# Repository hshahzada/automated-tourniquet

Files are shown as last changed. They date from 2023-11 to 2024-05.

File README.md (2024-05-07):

View this project on [CADLAB.io](https://cadlab.io/project/27395). 

# automated-tourniquet
2023/2024 Capstone Design Project for Biomedical Engineering

Created by:

Diana Temelkos dtemelkos@torontomu.ca
https://www.linkedin.com/in/dianatemelkos/

Hassan Khan hassan.a.khan@torontomu.ca
https://www.linkedin.com/in/hassan-khan-5604501a9/

Haashim Shahzada hshahzada@torontomu.ca
https://www.linkedin.com/in/haashimshahzada/

Sayeed Hasan sayeed.hasan@torontomu.ca
https://www.linkedin.com/in/sayeedhasanli/

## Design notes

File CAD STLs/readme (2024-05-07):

All files can be combined to simulate a replica DH3 Automated Tourniquet. 
All STLs were created using OnShape and 3D printed to create the design.

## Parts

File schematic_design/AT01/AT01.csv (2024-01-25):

Source: | D:\Haashim Shahzada\Documents\github\automated-tourniquet\schematic_design\AT01\AT01.kicad_sch
Date: | 1/21/2024 3:26:29 AM
Tool: | Eeschema 7.0.8
Generator: | C:\Program Files\KiCad\7.0\bin\scripting\plugins/bom_csv_grouped_by_value.py
Component Count: | 58
Collated Components:
Item | Qty | Reference(s) | Value | LibPart | Footprint | Datasheet | DNP
1 | 1 | C1 | 0.1uF | Device:C_Small | Capacitor_SMD:C_0402_1005Metric_Pad0.74x0.62mm_HandSolder | ~
2 | 1 | C2 | 1nF | Device:C_Small | Capacitor_SMD:C_0402_1005Metric_Pad0.74x0.62mm_HandSolder | ~
3 | 1 | C3 | 2.2uF | Device:C | Capacitor_SMD:C_0402_1005Metric_Pad0.74x0.62mm_HandSolder | ~
4 | 1 | C4 | 0.01uF | Device:C | Capacitor_SMD:C_0402_1005Metric_Pad0.74x0.62mm_HandSolder | ~
5 | 1 | C5 | 1uF | Device:C | Capacitor_SMD:C_0402_1005Metric_Pad0.74x0.62mm_HandSolder | ~
6 | 3 | C6, C8, C11 | 10uF | Device:C | Capacitor_SMD:C_0402_1005Metric_Pad0.74x0.62mm_HandSolder | ~
7 | 1 | C7 | 4.7uF | Device:C | Capacitor_SMD:C_0402_1005Metric_Pad0.74x0.62mm_HandSolder | ~
8 | 1 | C10 | 100uF | Device:C | Capacitor_SMD:C_0402_1005Metric_Pad0.74x0.62mm_HandSolder | ~
9 | 1 | C13 | 10uF | Device:C_Polarized_Small_US | Capacitor_SMD:C_1206_3216Metric_Pad1.33x1.80mm_HandSolder | ~
10 | 1 | C14 | 100uF | 2023-10-27_15-39-09:EEE-FN1A101UR | CAP_FN_C_PAN | EEE-FN1A101UR
11 | 2 | D1, D6 | B120-E3 | Diode:B120-E3 | Diode_SMD:D_SMA | http://www.vishay.com/docs/88946/b120.pdf
12 | 3 | D2, D7, D8 | LED | Device:LED | LED_THT:LED_D3.0mm | ~
13 | 3 | D3, D4, D5 | ESD9B3.3ST5G | Diode:ESD9B3.3ST5G | Diode_SMD:D_SOD-923 | https://www.onsemi.com/pub/Collateral/ESD9B-D.PDF
14 | 4 | H1, H2, H3, H4 | MountingHole | Mechanical:MountingHole | MountingHole:MountingHole_2.2mm_M2_ISO7380 | ~
15 | 1 | J1 | JST Connector | Connector:Screw_Terminal_01x02 | Connector_JST:JST_EH_S2B-EH_1x02_P2.50mm_Horizontal | ~
16 | 1 | J2 | Conn_01x08 | Connector_Generic:Conn_01x08 | Connector_PinHeader_1.00mm:PinHeader_1x08_P1.00mm_Vertical | ~
17 | 1 | J3 | USB_C_Receptacle_USB2.0 | Connector:USB_C_Receptacle_USB2.0 | Connector_USB:USB_C_Receptacle_HRO_TYPE-C-31-M-12 | https://www.usb.org/sites/default/files/documents/usb_type-c.zip
18 | 1 | J4 | DC Pump Connector | Connector:Screw_Terminal_01x02 | TerminalBlock_4Ucon:TerminalBlock_4Ucon_1x02_P3.50mm_Vertical | ~
19 | 1 | J5 | Solenoid Valve Connector | Connector:Screw_Terminal_01x02 | TerminalBlock_4Ucon:TerminalBlock_4Ucon_1x02_P3.50mm_Vertical | ~
20 | 1 | Q1 | DMG2301L | Transistor_FET:DMG2301L | Package_TO_SOT_SMD:SOT-23 | https://www.diodes.com/assets/Datasheets/DMG2301L.pdf
21 | 2 | Q2, Q3 | 2N7002 | Transistor_FET:2N7002 | Package_TO_SOT_SMD:SOT-23 | https://www.onsemi.com/pub/Collateral/NDS7002A-D.PDF
22 | 8 | R1, R5, R6, R7, R9, R10, R14, R15 | 5.1K | Device:R | Resistor_SMD:R_0402_1005Metric_Pad0.72x0.64mm_HandSolder | ~
23 | 3 | R2, R12, R13 | 2.2K | Device:R | Resistor_SMD:R_0402_1005Metric_Pad0.72x0.64mm_HandSolder | ~
24 | 1 | R3 | 100K | Device:R | Resistor_SMD:R_0402_1005Metric_Pad0.72x0.64mm_HandSolder | ~
25 | 4 | R4, R11, R16, R17 | 10K | Device:R | Resistor_SMD:R_0402_1005Metric_Pad0.72x0.64mm_HandSolder | ~
26 | 1 | R8 | 20K | Device:R | Resistor_SMD:R_0402_1005Metric_Pad0.72x0.64mm_HandSolder | ~
27 | 3 | SW1, SW2, SW3 | SW_Push | Switch:SW_Push | Button_Switch_THT:SW_PUSH_6mm | ~
28 | 1 | U1 | MPRLS0025PA00001A | MPRLS0025PA00001A:MPRLS0025PA00001A | MPRLS_HNW | MPRLS0025PA00001A
29 | 1 | U2 | FT232RL | Interface_USB:FT232RL | Package_SO:SSOP-28_5.3x10.2mm_P0.65mm | https://www.ftdichip.com/Support/Documents/DataSheets/ICs/DS_FT232R.pdf
30 | 1 | U3 | DRV8833PW | Driver_Motor:DRV8833PW | Package_SO:TSSOP-16_4.4x5mm_P0.65mm | http://www.ti.com/lit/ds/symlink/drv8833.pdf
31 | 1 | U4 | MCP73831-2-OT | Battery_Management:MCP73831-2-OT | Package_TO_SOT_SMD:SOT-23-5 | http://ww1.microchip.com/downloads/en/DeviceDoc/20001984g.pdf
32 | 1 | U5 | ESP32-WROOM-32 | RF_Module:ESP32-WROOM-32U | RF_Module:ESP32-WROOM-32UE | https://www.espressif.com/sites/default/files/documentation/esp32-wroom-32d_esp32-wroom-32u_datasheet_en.pdf
33 | 1 | U6 | LM1117MP-3.3 | Regulator_Linear:LM1117MP-3.3 | Package_TO_SOT_SMD:SOT-223-3_TabPin2 | http://www.ti.com/lit/ds/symlink/lm1117.pdf

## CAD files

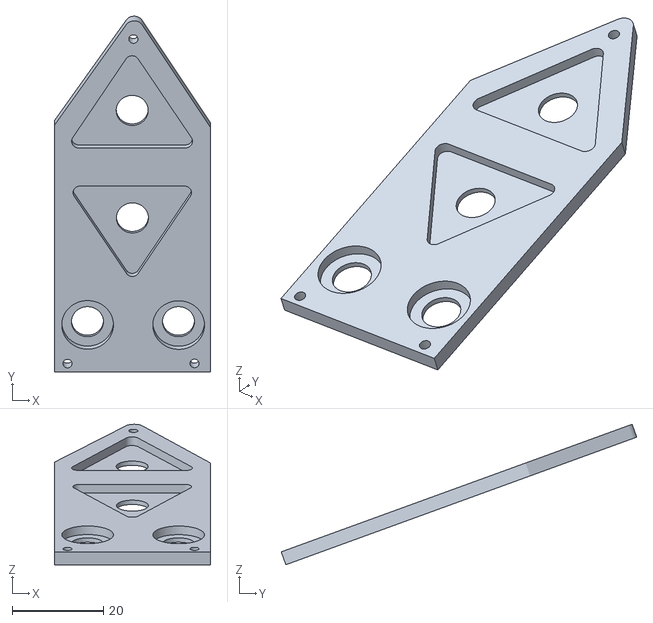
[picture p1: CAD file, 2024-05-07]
CAD STLs/AT01 - button setter.stl
34.1 x 77.8 x 30.8

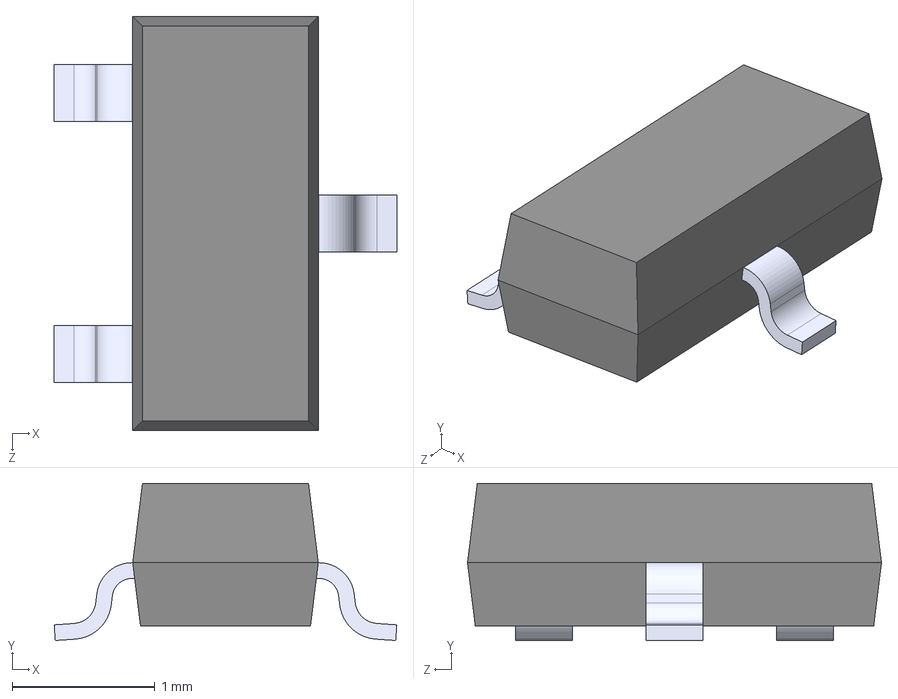
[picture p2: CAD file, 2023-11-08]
schematic_design/AT01/DMG3415U-7/DMG3415U-7.step
2.40 x 1.10 x 2.90 mm

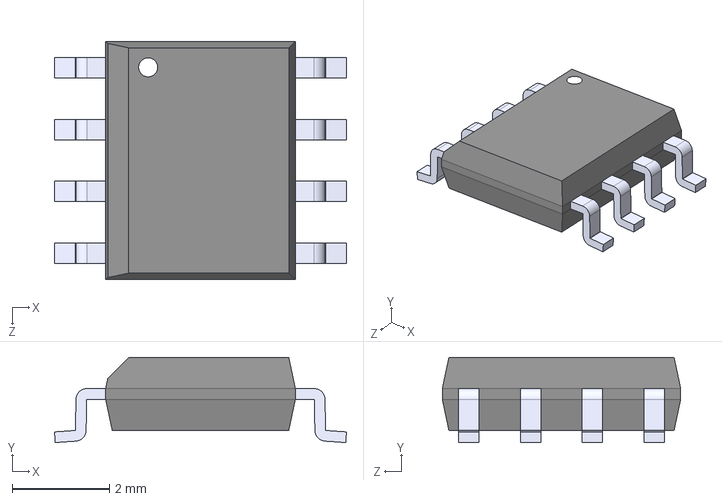
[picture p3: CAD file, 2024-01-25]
schematic_design/AT01/FDS6375/FDS6375.step
6.00 x 1.75 x 4.90 mm

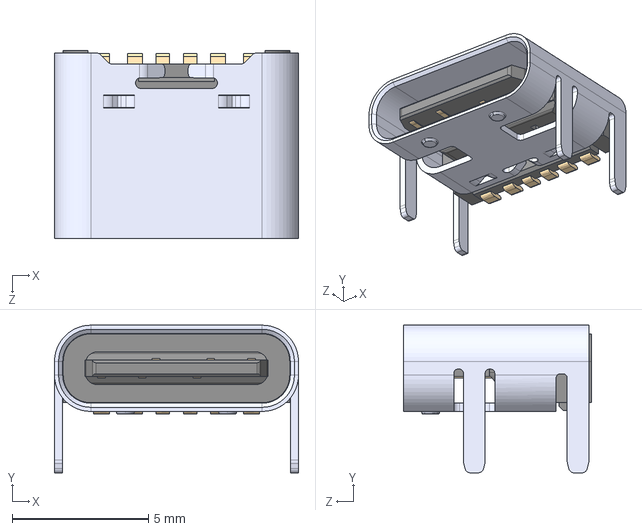
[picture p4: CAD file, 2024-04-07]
schematic_design/AT01/USB4125_GF_A_0190/USB4125-GF-A-0190_REVA2.step
8.94 x 5.41 x 6.90 mm

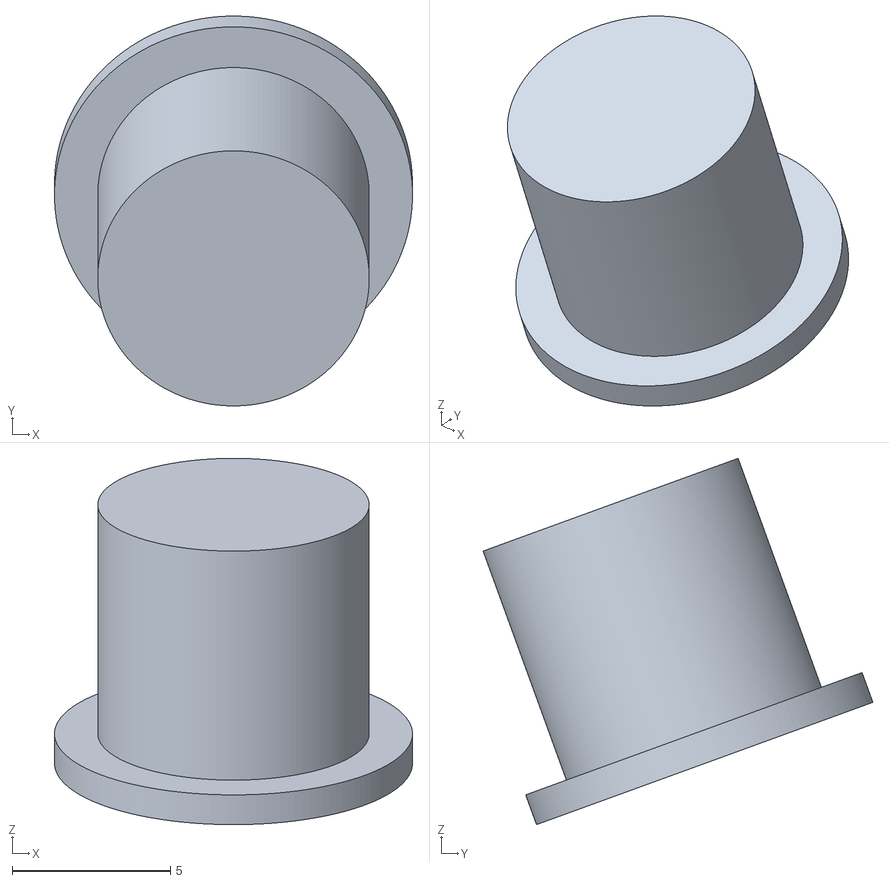
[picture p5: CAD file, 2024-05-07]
CAD STLs/AT01 - power.stl
11.3 x 12.3 x 11.6

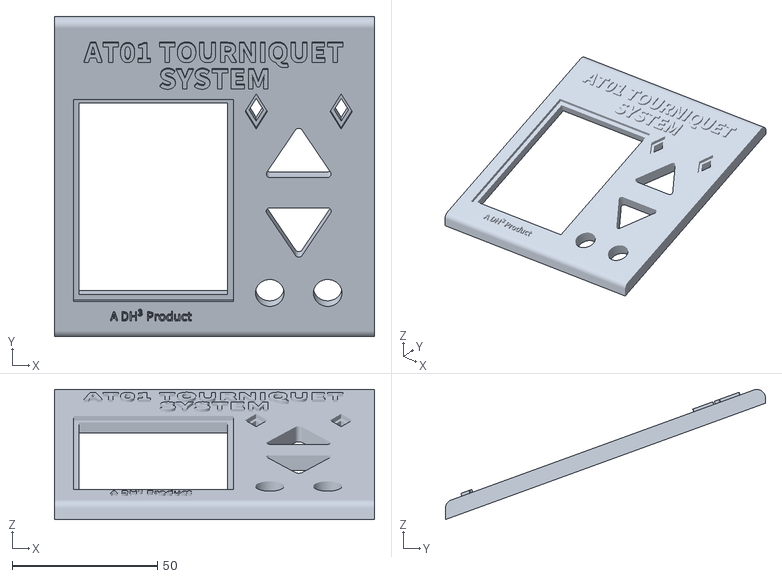
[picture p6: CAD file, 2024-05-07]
CAD STLs/AT01 - top-cover.stl
110.0 x 110.0 x 44.7

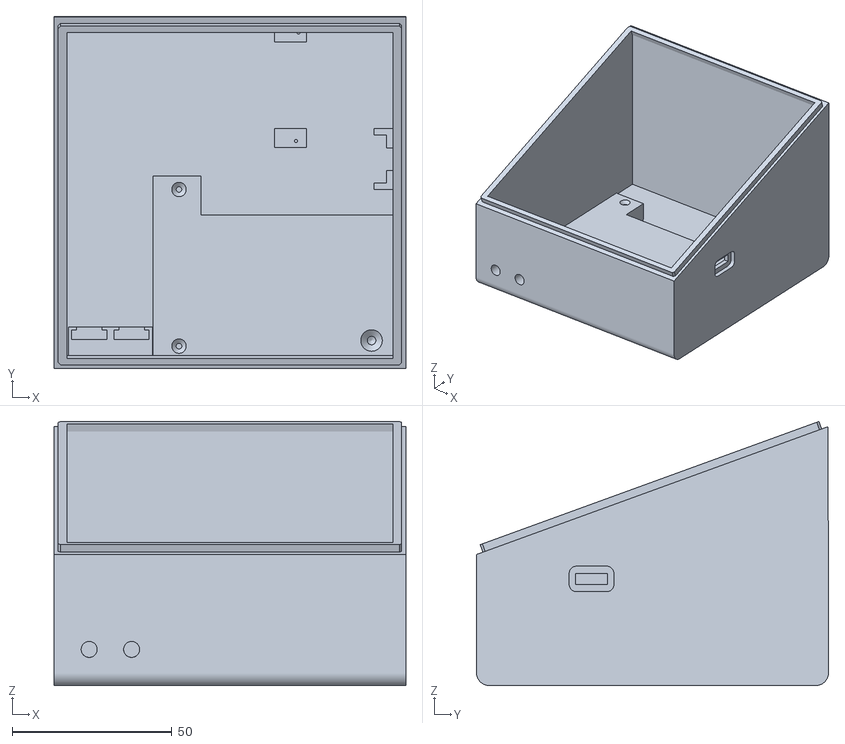
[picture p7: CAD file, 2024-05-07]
CAD STLs/AT01 - bottom.stl
110.0 x 110.1 x 82.6

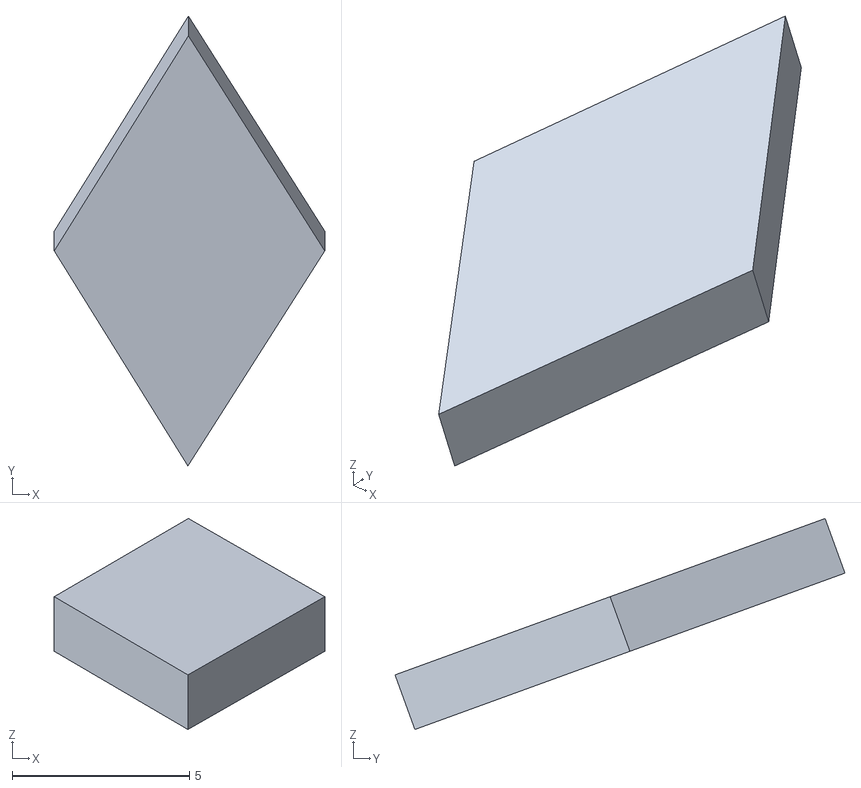
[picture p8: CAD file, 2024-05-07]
CAD STLs/AT01 - light 1 cover.stl
7.63 x 12.7 x 5.96

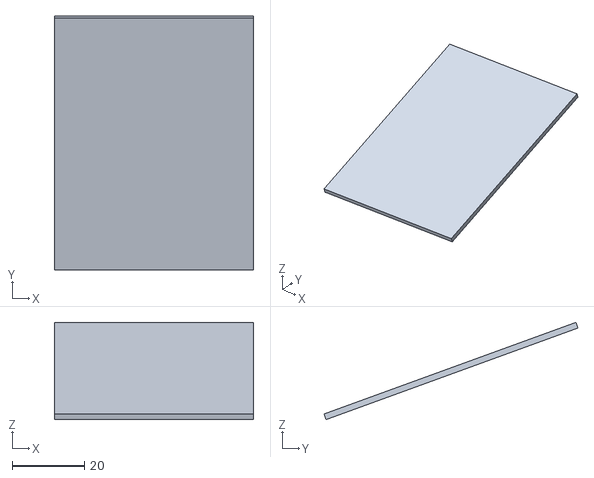
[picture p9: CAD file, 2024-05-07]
CAD STLs/AT01 - display protector.stl
55.0 x 70.1 x 26.8

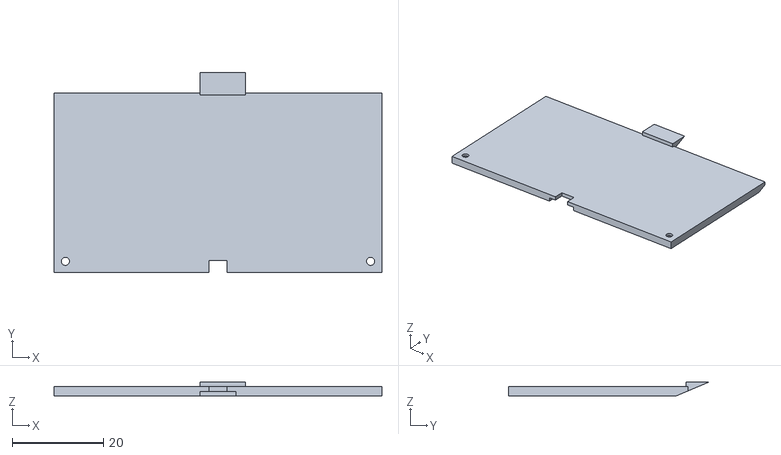
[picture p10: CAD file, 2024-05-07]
CAD STLs/AT01 - battery cover.stl
72.0 x 44.0 x 3.00

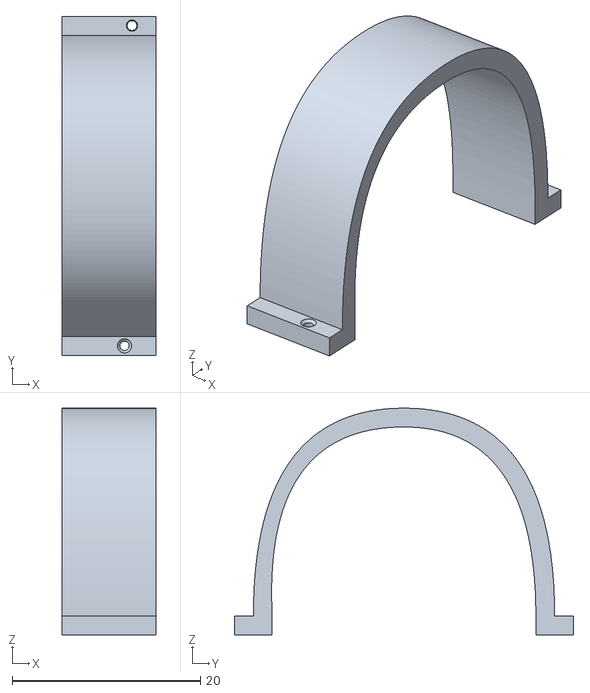
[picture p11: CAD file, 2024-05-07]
CAD STLs/AT01 - fastener.stl
10.0 x 36.0 x 24.1

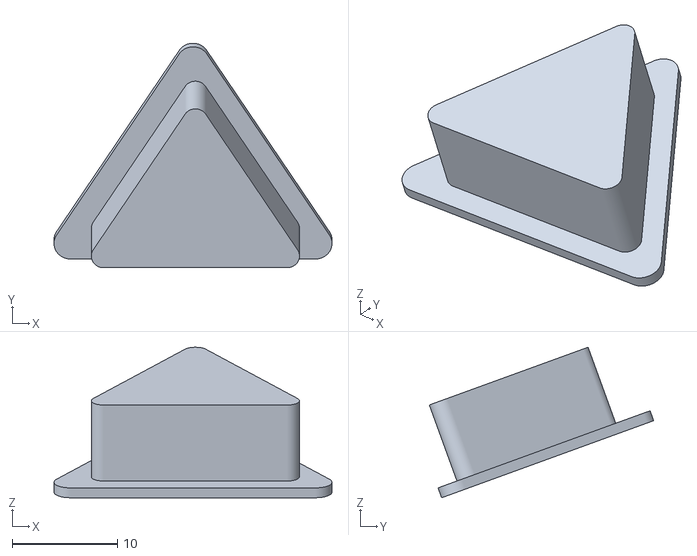
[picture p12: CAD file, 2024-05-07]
CAD STLs/AT01 - down.stl
26.5 x 21.4 x 14.3

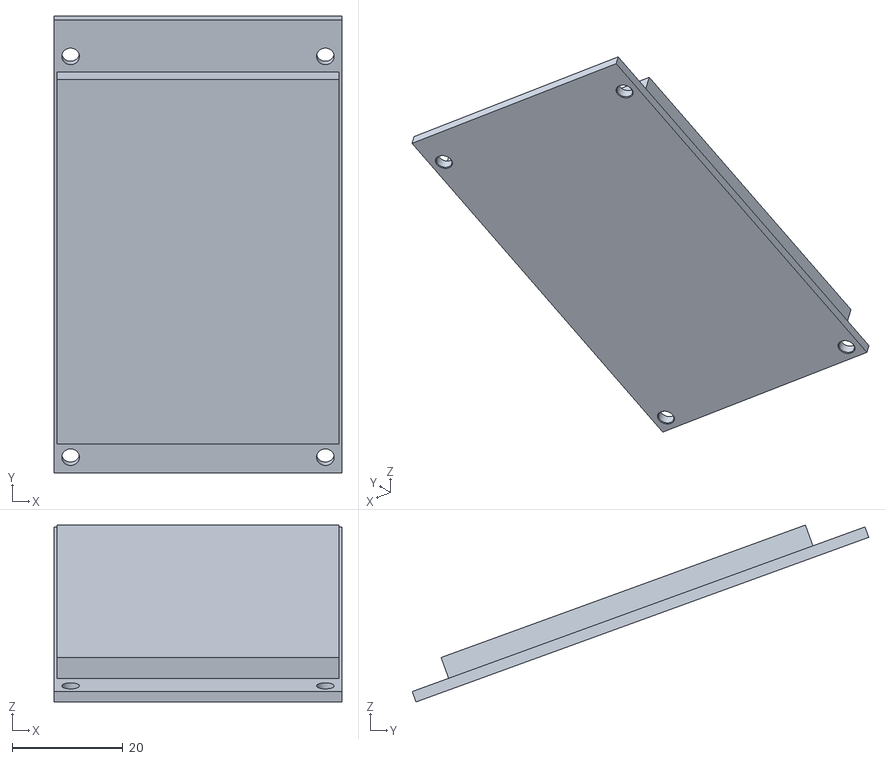
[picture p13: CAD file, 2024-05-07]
CAD STLs/AT01 - display.stl
52.0 x 82.4 x 32.0

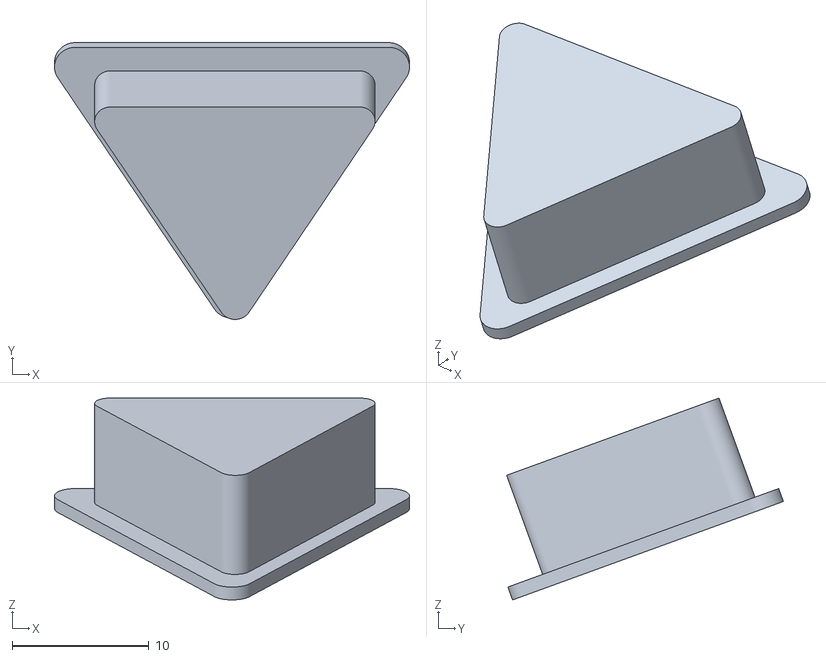
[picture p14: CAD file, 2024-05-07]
CAD STLs/AT01 - up.stl
25.9 x 20.2 x 14.7

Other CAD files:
CAD STLs/AT01 - reset.stl
CAD STLs/AT01 - internal pneum inlet 2.stl
CAD STLs/AT01 - pcb.stl
CAD STLs/AT01 - internal pneum inlet 1.stl
CAD STLs/AT01 - cuff inlet piece.stl
CAD STLs/AT01 - light 2 cover.stl

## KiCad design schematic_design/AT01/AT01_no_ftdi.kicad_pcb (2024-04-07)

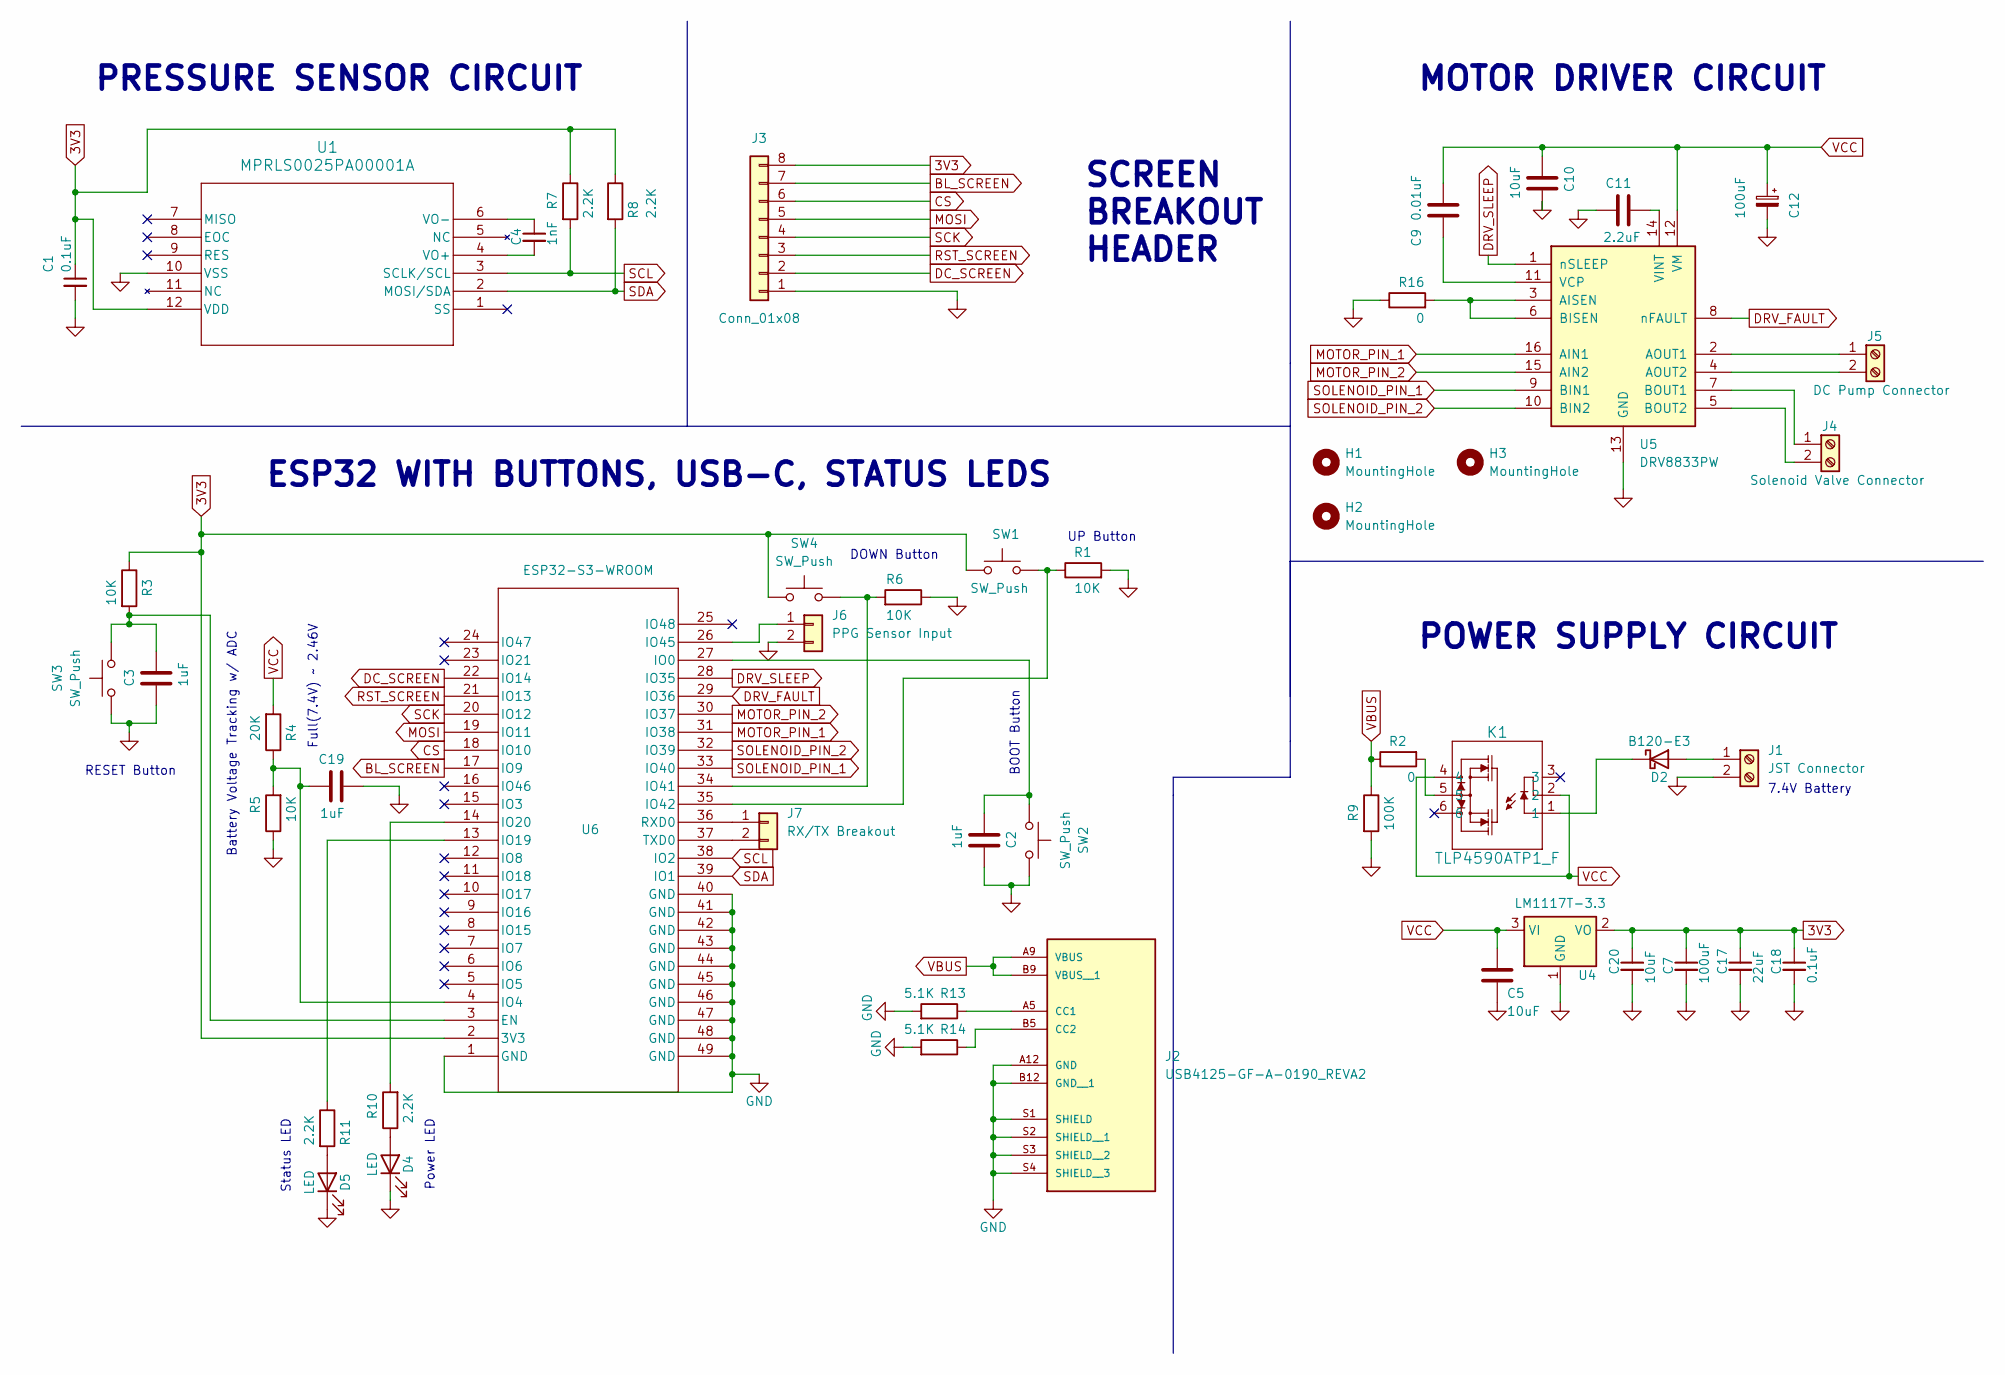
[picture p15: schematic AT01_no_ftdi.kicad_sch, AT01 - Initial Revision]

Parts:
C1, C18: 0.1uF; C_0603_1608Metric_Pad1.08x0.95mm_HandSolder
C2, C3, C19: 1uF; C_0603_1608Metric_Pad1.08x0.95mm_HandSolder
C4: 1nF; C_0603_1608Metric_Pad1.08x0.95mm_HandSolder
C5, C10, C20: 10uF; C_0603_1608Metric_Pad1.08x0.95mm_HandSolder
C7: 100uF; C_0805_2012Metric_Pad1.18x1.45mm_HandSolder
C9: 0.01uF; C_0603_1608Metric_Pad1.08x0.95mm_HandSolder
C11: 2.2uF; C_0603_1608Metric_Pad1.08x0.95mm_HandSolder
C12: 100uF; CP_Elec_6.3x5.2
C17: 22uF; C_0603_1608Metric_Pad1.08x0.95mm_HandSolder
D2: B120-E3; D_SMA
D4, D5: LED; LED_D3.0mm
H1, H2, H3: MountingHole; MountingHole_2.2mm_M2_ISO7380
J1: JST Connector; JST_EH_S2B-EH_1x02_P2.50mm_Horizontal
J2: USB4125-GF-A-0190_REVA2; GCT_USB4125-GF-A-0190_REVA2; PARTREV Rev A2
J3: Conn_01x08; PinHeader_1x08_P2.54mm_Vertical
J4: Solenoid Valve Connector; TerminalBlock_4Ucon_1x02_P3.50mm_Horizontal
J5: DC Pump Connector; TerminalBlock_4Ucon_1x02_P3.50mm_Horizontal
J6: PPG Sensor Input; PinHeader_1x02_P2.54mm_Vertical
J7: RX/TX Breakout; PinHeader_1x02_P2.54mm_Vertical
K1: TLP4590ATP1_F; 11-7A801S_TOS
R1, R3, R5, R6: 10K; R_0603_1608Metric_Pad0.98x0.95mm_HandSolder
R2, R16: 0; R_0603_1608Metric_Pad0.98x0.95mm_HandSolder
R4: 20K; R_0603_1608Metric_Pad0.98x0.95mm_HandSolder
R7, R8, R10, R11: 2.2K; R_0603_1608Metric_Pad0.98x0.95mm_HandSolder
R9: 100K; R_0603_1608Metric_Pad0.98x0.95mm_HandSolder
R13, R14: 5.1K; R_0603_1608Metric_Pad0.98x0.95mm_HandSolder
SW1, SW2, SW3, SW4: SW_Push; SW_PUSH_6mm
U1: MPRLS0025PA00001A; MPRLS_HNW
U4: LM1117T-3.3; TO-220-3_Horizontal_TabDown
U5: DRV8833PW; TSSOP-16_4.4x5mm_P0.65mm
U6: ESP32-S3-WROOM; ESP32-S3-WROOM-1U

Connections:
3V3: C1.1, C7.1, C17.1, C18.1, C20.1, J3.8, R3.1, R7.1, R8.1, SW1.1, SW4.1, U1.12 (VDD), U4.2 (VO), U6.2 (3V3)
BL_SCREEN: J3.7, U6.17 (IO9)
CS: J3.6, U6.18 (IO10)
DC_SCREEN: J3.2, U6.22 (IO14)
DRV_FAULT: U5.8 (nFAULT), U6.29 (IO36)
DRV_SLEEP: U5.1 (nSLEEP), U6.28 (IO35)
GND: C1.2, C2.2, C3.2, C5.2, C7.2, C10.1, C11.1, C12.2, C17.2, C18.2, C19.2, C20.2, D4.1 (K), D5.1 (K), J1.2, J2.A12 (GND), J2.B12 (GND__1), J2.S1 (SHIELD), J2.S2 (SHIELD__1), J2.S3 (SHIELD__2), J2.S4 (SHIELD__3), J3.1, J6.2, R1.2, R5.1, R6.1, R9.2, R13.2, R14.2, R16.1, SW2.2, SW3.2, U1.10 (VSS), U4.1 (GND), U5.13 (GND), U6.1 (GND), U6.40 (GND), U6.41 (GND), U6.42 (GND), U6.43 (GND), U6.44 (GND), U6.45 (GND), U6.46 (GND), U6.47 (GND), U6.48 (GND), U6.49 (GND)
MOSI: J3.5, U6.19 (IO11)
MOTOR_PIN_1: U5.16 (AIN1), U6.31 (IO38)
MOTOR_PIN_2: U5.15 (AIN2), U6.30 (IO37)
unnamed: D2.2 (A), J1.1
unnamed: D2.1 (K), K1.1
unnamed: D4.2 (A), R10.1
unnamed: D5.2 (A), R11.2
unnamed: J2.A5 (CC1), R13.1
unnamed: J2.B5 (CC2), R14.1
unnamed: J4.1, U5.7 (BOUT1)
unnamed: J4.2, U5.5 (BOUT2)
unnamed: J5.1, U5.2 (AOUT1)
unnamed: J5.2, U5.4 (AOUT2)
unnamed: J6.1, U6.26 (IO45)
unnamed: J7.1, U6.36 (RXD0)
unnamed: J7.2, U6.37 (TXD0)
unnamed: K1.5, R2.2
unnamed: C4.2, U1.4 (VO+)
unnamed: C4.1, U1.6 (VO-)
unnamed: R16.2, U5.3 (AISEN), U5.6 (BISEN)
unnamed: C9.1, U5.11 (VCP)
unnamed: C11.2, U5.14 (VINT)
unnamed: C3.1, R3.2, SW3.1, U6.3 (EN)
unnamed: C2.1, SW2.1, U6.27 (IO0)
unnamed: C19.1, R4.1, R5.2, U6.4 (IO4)
unnamed: R11.1, U6.13 (IO19)
unnamed: R10.2, U6.14 (IO20)
unnamed: R6.2, SW4.2, U6.34 (IO41)
unnamed: R1.1, SW1.2, U6.35 (IO42)
RST_SCREEN: J3.3, U6.21 (IO13)
SCK: J3.4, U6.20 (IO12)
SCL: R7.2, U1.3 (SCLK/SCL), U6.38 (IO2)
SDA: R8.2, U1.2 (MOSI/SDA), U6.39 (IO1)
SOLENOID_PIN_1: U5.9 (BIN1), U6.33 (IO40)
SOLENOID_PIN_2: U5.10 (BIN2), U6.32 (IO39)
VBUS: J2.A9 (VBUS), J2.B9 (VBUS__1), R2.1, R9.1
VCC: C5.1, C9.2, C10.2, C12.1, K1.2, K1.4, R4.2, U4.3 (VI), U5.12 (VM)

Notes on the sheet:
UP Button
Full(7.4V) ~ 2.46V
PRESSURE SENSOR CIRCUIT
RESET Button
POWER SUPPLY CIRCUIT
7.4V Battery
ESP32 WITH BUTTONS, USB-C, STATUS LEDS
Power LED
SCREEN BREAKOUT HEADER
BOOT Button
MOTOR DRIVER CIRCUIT
DOWN Button
Battery Voltage Tracking w/ ADC
Status LED

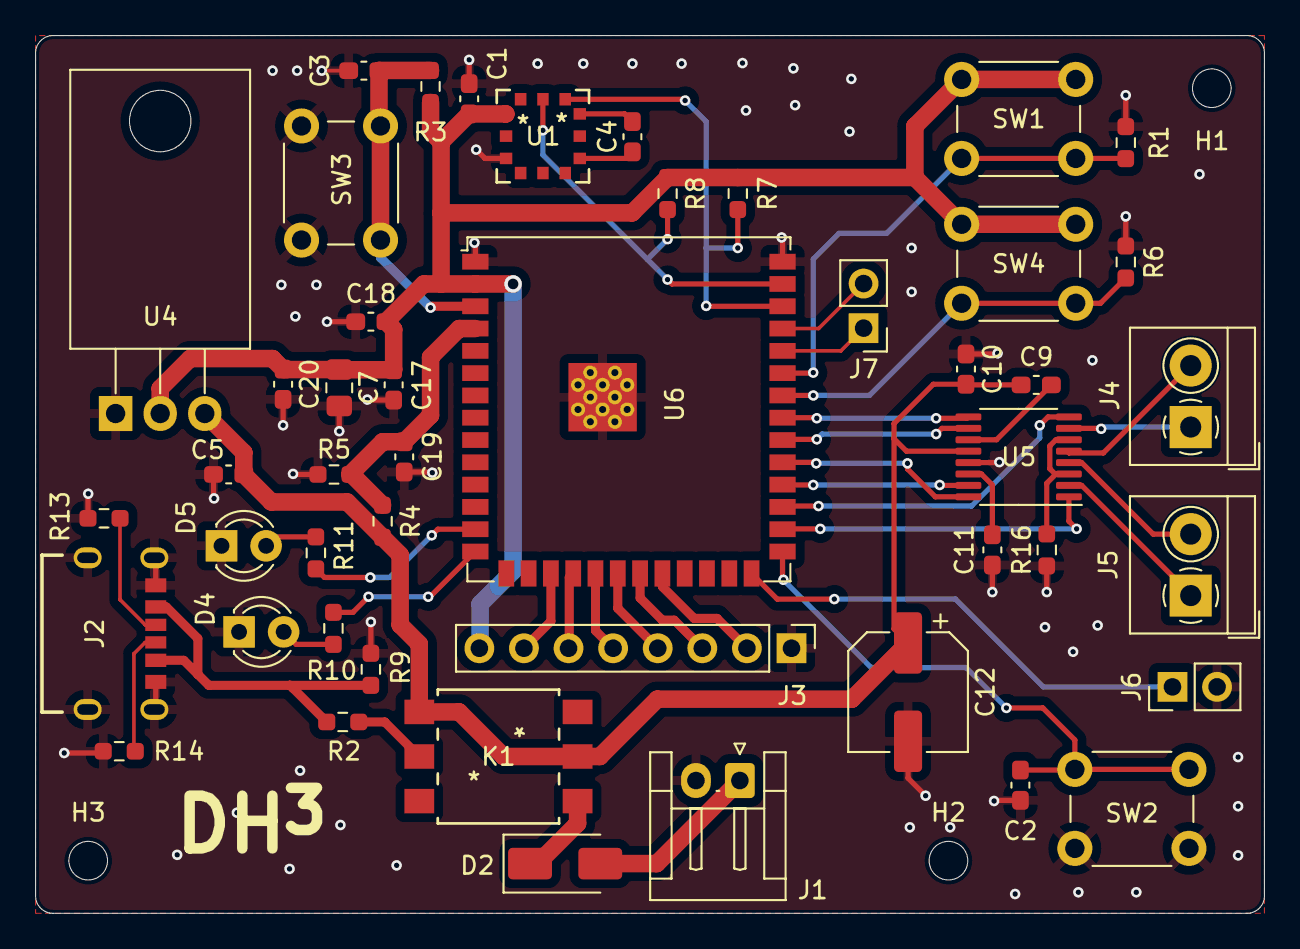
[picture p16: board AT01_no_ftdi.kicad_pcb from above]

Board: 2 copper layers, 70.0 x 50.0 mm, 50 parts (0 on the bottom side), 44 nets.

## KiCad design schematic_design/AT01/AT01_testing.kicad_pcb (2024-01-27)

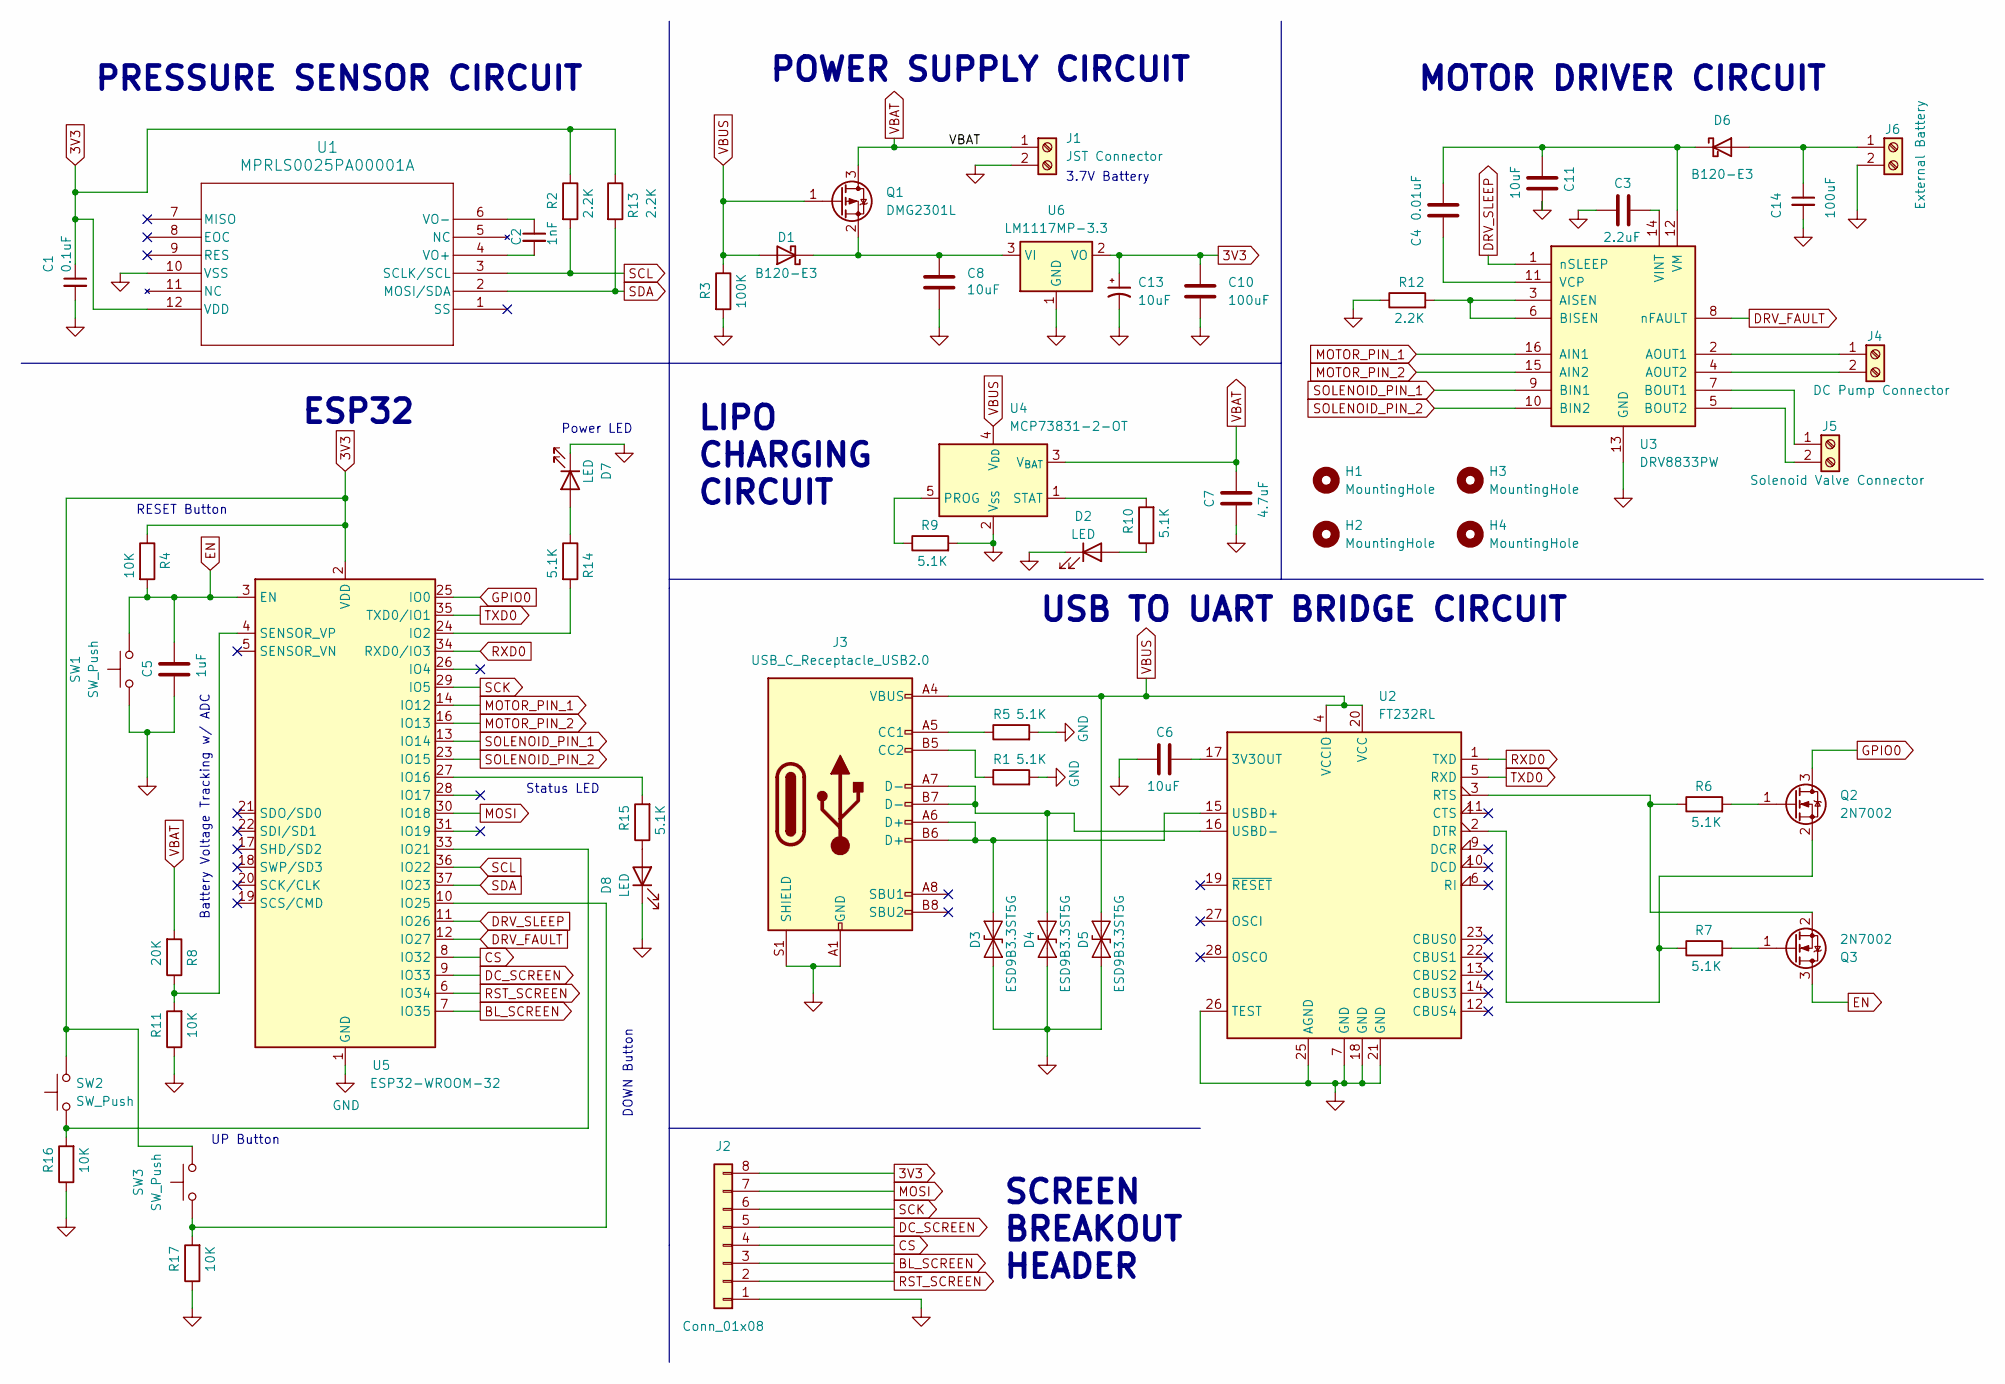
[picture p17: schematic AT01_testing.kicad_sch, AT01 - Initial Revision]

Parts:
C1: 0.1uF; C_0402_1005Metric_Pad0.74x0.62mm_HandSolder
C2: 1nF; C_0402_1005Metric_Pad0.74x0.62mm_HandSolder
C3: 2.2uF; C_0402_1005Metric_Pad0.74x0.62mm_HandSolder
C4: 0.01uF; C_0402_1005Metric_Pad0.74x0.62mm_HandSolder
C5: 1uF; C_0402_1005Metric_Pad0.74x0.62mm_HandSolder
C6, C8, C11: 10uF; C_0402_1005Metric_Pad0.74x0.62mm_HandSolder
C7: 4.7uF; C_0402_1005Metric_Pad0.74x0.62mm_HandSolder
C10, C14: 100uF; C_0402_1005Metric_Pad0.74x0.62mm_HandSolder
C13: 10uF; C_1206_3216Metric_Pad1.33x1.80mm_HandSolder
D1, D6: B120-E3; D_SMA
D2, D7, D8: LED; LED_D3.0mm
D3, D4, D5: ESD9B3.3ST5G; D_SOD-923
H1, H2, H3, H4: MountingHole; MountingHole_2.2mm_M2_ISO7380
J1: JST Connector; JST_EH_S2B-EH_1x02_P2.50mm_Horizontal
J2: Conn_01x08; PinHeader_1x08_P1.00mm_Vertical
J3: USB_C_Receptacle_USB2.0; USB_C_Receptacle_HRO_TYPE-C-31-M-12
J4: DC Pump Connector; TerminalBlock_4Ucon_1x02_P3.50mm_Horizontal
J5: Solenoid Valve Connector; TerminalBlock_4Ucon_1x02_P3.50mm_Horizontal
J6: External Battery; TerminalBlock_4Ucon_1x02_P3.50mm_Horizontal
Q1: DMG2301L; SOT-23
Q2, Q3: 2N7002; SOT-23
R1, R5, R6, R7, R9, R10, R14, R15: 5.1K; R_0402_1005Metric_Pad0.72x0.64mm_HandSolder
R2, R12, R13: 2.2K; R_0402_1005Metric_Pad0.72x0.64mm_HandSolder
R3: 100K; R_0402_1005Metric_Pad0.72x0.64mm_HandSolder
R4, R11, R16, R17: 10K; R_0402_1005Metric_Pad0.72x0.64mm_HandSolder
R8: 20K; R_0402_1005Metric_Pad0.72x0.64mm_HandSolder
SW1, SW2, SW3: SW_Push; SW_PUSH_6mm
U1: MPRLS0025PA00001A; MPRLS_HNW
U2: FT232RL; SSOP-28_5.3x10.2mm_P0.65mm
U3: DRV8833PW; TSSOP-16_4.4x5mm_P0.65mm
U4: MCP73831-2-OT; SOT-23-5
U5: ESP32-WROOM-32; ESP32-WROOM-32UE
U6: LM1117MP-3.3; SOT-223-3_TabPin2

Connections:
3V3: C1.1, C10.1, C13.1, J2.8, R2.1, R4.1, R13.1, SW2.1, SW3.1, U1.12 (VDD), U5.2 (VDD), U6.2 (VO)
BL_SCREEN: J2.3, U5.7 (IO35)
CS: J2.4, U5.8 (IO32)
DC_SCREEN: J2.5, U5.9 (IO33)
DRV_FAULT: U3.8 (nFAULT), U5.12 (IO27)
DRV_SLEEP: U3.1 (nSLEEP), U5.11 (IO26)
EN: C5.1, Q3.3 (D), R4.2, SW1.1, U5.3 (EN)
GND: C1.2, C3.1, C5.2, C6.2, C7.1, C8.2, C10.2, C11.1, C13.2, C14.2, D2.1 (K), D3.1 (A1), D4.1 (A1), D5.1 (A1), D7.1 (K), D8.1 (K), J1.2, J2.1, J3.A1 (GND), J3.A12 (GND), J3.B1 (GND), J3.B12 (GND), J3.S1 (SHIELD), J6.2, R1.2, R3.2, R5.2, R9.2, R11.1, R12.1, R16.1, R17.1, SW1.2, U1.10 (VSS), U2.7 (GND), U2.18 (GND), U2.21 (GND), U2.25 (AGND), U2.26 (TEST), U3.13 (GND), U4.2 (V_{SS}), U5.1 (GND), U5.15 (GND), U5.38 (GND), U5.39 (GND), U6.1 (GND)
GPIO0: Q2.3 (D), U5.25 (IO0)
MOSI: J2.7, U5.30 (IO18)
MOTOR_PIN_1: U3.16 (AIN1), U5.14 (IO12)
MOTOR_PIN_2: U3.15 (AIN2), U5.16 (IO13)
unnamed: C8.1, D1.1 (K), Q1.2 (S), U6.3 (VI)
unnamed: D2.2 (A), R10.1
unnamed: D3.2 (A2), J3.A6 (D+), J3.B6 (D+), U2.15 (USBD+)
unnamed: D4.2 (A2), J3.A7 (D-), J3.B7 (D-), U2.16 (USBD-)
unnamed: C14.1, D6.2 (A), J6.1
unnamed: C4.2, C11.2, D6.1 (K), U3.12 (VM)
unnamed: D7.2 (A), R14.1
unnamed: D8.2 (A), R15.1
unnamed: J3.A5 (CC1), R5.1
unnamed: J3.B5 (CC2), R1.1
unnamed: J4.1, U3.2 (AOUT1)
unnamed: J4.2, U3.4 (AOUT2)
unnamed: J5.1, U3.7 (BOUT1)
unnamed: J5.2, U3.5 (BOUT2)
unnamed: Q2.1 (G), R6.2
unnamed: Q2.2 (S), R7.1, U2.2 (DTR)
unnamed: Q3.1 (G), R7.2
unnamed: Q3.2 (S), R6.1, U2.3 (RTS)
unnamed: C2.2, U1.4 (VO+)
unnamed: C2.1, U1.6 (VO-)
unnamed: C6.1, U2.17 (3V3OUT)
unnamed: R12.2, U3.3 (AISEN), U3.6 (BISEN)
unnamed: C4.1, U3.11 (VCP)
unnamed: C3.2, U3.14 (VINT)
unnamed: R9.1, U4.5 (PROG)
unnamed: R10.2, U4.1 (STAT)
unnamed: R14.2, U5.24 (IO2)
unnamed: R15.2, U5.27 (IO16)
unnamed: R16.2, SW2.2, U5.33 (IO21)
unnamed: R17.2, SW3.2, U5.10 (IO25)
unnamed: R8.1, R11.2, U5.4 (SENSOR_VP)
RST_SCREEN: J2.2, U5.6 (IO34)
RXD0: U2.1 (TXD), U5.34 (RXD0/IO3)
SCK: J2.6, U5.29 (IO5)
SCL: R2.2, U1.3 (SCLK/SCL), U5.36 (IO22)
SDA: R13.2, U1.2 (MOSI/SDA), U5.37 (IO23)
SOLENOID_PIN_1: U3.9 (BIN1), U5.13 (IO14)
SOLENOID_PIN_2: U3.10 (BIN2), U5.23 (IO15)
TXD0: U2.5 (RXD), U5.35 (TXD0/IO1)
VBAT: C7.2, J1.1, Q1.3 (D), R8.2, U4.3 (V_{BAT})
VBUS: D1.2 (A), D5.2 (A2), J3.A4 (VBUS), J3.A9 (VBUS), J3.B4 (VBUS), J3.B9 (VBUS), Q1.1 (G), R3.1, U2.4 (VCCIO), U2.20 (VCC), U4.4 (V_{DD})

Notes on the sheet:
LIPO CHARGING CIRCUIT
PRESSURE SENSOR CIRCUIT
RESET Button
Power LED
POWER SUPPLY CIRCUIT
UP Button
3.7V Battery
ESP32
USB TO UART BRIDGE CIRCUIT
SCREEN BREAKOUT HEADER
MOTOR DRIVER CIRCUIT
Status LED
DOWN Button
Battery Voltage Tracking w/ ADC

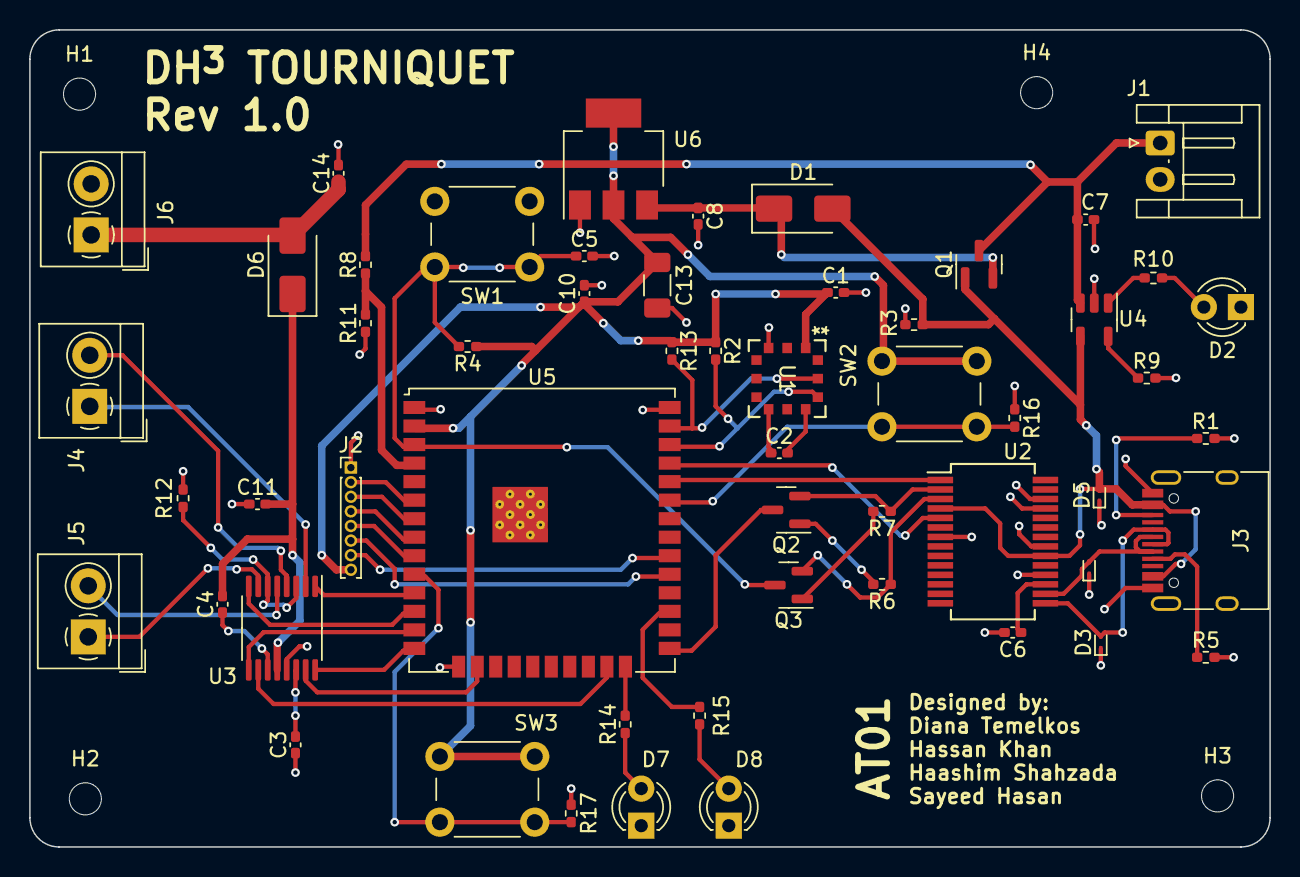
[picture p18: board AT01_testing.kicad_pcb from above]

Board: 2 copper layers, 85.0 x 56.0 mm, 59 parts (0 on the bottom side), 53 nets.

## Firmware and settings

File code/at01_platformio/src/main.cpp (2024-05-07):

#include <lvgl.h>
#include <TFT_eSPI.h>
#include <Wire.h>
#include <Adafruit_I2CDevice.h>
#include "Adafruit_MPRLS.h"
#include <PID_v1.h>
#include <WiFi.h>
#include "time.h"
//#include <examples/lv_examples.h>
//#include <demos/lv_demos.h>

/*Set to your screen resolution and rotation*/
#define TFT_HOR_RES   240
#define TFT_VER_RES   320
#define TFT_ROTATION  LV_DISPLAY_ROTATION_0

/*LVGL draw into this buffer, 1/10 screen size usually works well. The size is in bytes*/
#define DRAW_BUF_SIZE (TFT_HOR_RES * TFT_VER_RES / 10 * (LV_COLOR_DEPTH / 8))
uint32_t draw_buf[DRAW_BUF_SIZE / 4];

static uint32_t lvgl_refresh_timestamp = 0u;
#define LVGL_REFRESH_TIME 5u

const char* ssid       = "HaashimPixel";
const char* password   = "12345678";

const char* ntp_server = "pool.ntp.org";
const long  gmt_offset_sec = -18000;
const int   daylight_offset_sec = 3600;

// You dont *need* a reset and EOC pin for most uses, so we set to -1 and don't connect
#define RESET_PIN  -1  // set to any GPIO pin # to hard-reset on begin()
#define EOC_PIN    -1  // set to any GPIO pin to read end-of-conversion by pin
#define UP_BUTTON 42
#define DOWN_BUTTON 41
#define SOLENOID_PIN  37
#define MOTOR_PIN  39
#define LED1_PIN -1
#define LED2_PIN -1
#define SLEEP_PIN 35
#define BL_PIN 9
#define STATUS_LED 19
#define POWER_LED 20

const float VENEPUNCTURE_PRESSURE = 60;
const float BICEP_PRESSURE = 203;
const float THIGH_PRESSURE = 300;
float current_pressure;
float target_pressure;

const unsigned long VENEPUNCTURE_TIME = 60000;
const unsigned long BICEP_TIME = 5400000;
const unsigned long THIGH_TIME = 7200000;
unsigned long start_time = 0;
unsigned long target_time = 0;

Adafruit_MPRLS mpr = Adafruit_MPRLS(RESET_PIN, EOC_PIN);

// PID Setup
double PID_pressure;
double Input, Output;
float calibration_value;
double Kp = 3, Ki = 0.05, Kd = 1; // Example PID tuning values, adjust as needed
PID myPID(&Input, &Output, &PID_pressure, Kp, Ki, Kd, DIRECT);

void home_screen();
void actuation_screen(const char *mode);
void occlusion_screen();

LV_IMAGE_DECLARE(arrow_up);
LV_IMAGE_DECLARE(arrow_down);

lv_obj_t *pressure_val;
lv_obj_t *vene_label;
lv_obj_t * bar;
lv_timer_t * bar_timer;
int bar_value;
char current_pressure_label[6];
bool timer_on = false;
int pressure_time;
bool time_started = false;
struct tm timeinfo;

#if LV_USE_LOG != 0
void my_print( lv_log_level_t level, const char * buf )
{
  LV_UNUSED(level);
  Serial.println(buf);
  Serial.flush();
}
#endif

/* LVGL calls it when a rendered image needs to copied to the display*/
void my_disp_flush( lv_display_t *disp, const lv_area_t *area, uint8_t * px_map)
{
  /*Call it to tell LVGL you are ready*/
  lv_display_flush_ready(disp);
}

/*use Arduinos millis() as tick source*/
static uint32_t my_tick(void)
{
  return millis();
}

static void occlusion_up_pressed(lv_event_t * event)
{
  //Original Code
  lv_event_code_t code = lv_event_get_code(event);

  if(code == LV_EVENT_PRESSED) 
  {
    target_pressure = BICEP_PRESSURE;
    bar_value = (int)BICEP_TIME/1000;
    target_time = BICEP_TIME;
    actuation_screen("Bicep Occlusion");
  }
}

static void occlusion_down_pressed(lv_event_t * event)
{
  //Original Code
  lv_event_code_t code = lv_event_get_code(event);

  if(code == LV_EVENT_PRESSED) 
  {
    target_pressure = THIGH_PRESSURE;
    bar_value = (int)THIGH_TIME/1000;
    target_time = THIGH_TIME;
    actuation_screen("Thigh Occlusion");
  }
}

static void up_pressed(lv_event_t * event)
{
  //Original Code
  lv_event_code_t code = lv_event_get_code(event);

  if(code == LV_EVENT_PRESSED) 
  {
    target_pressure = VENEPUNCTURE_PRESSURE;
    bar_value = (int)VENEPUNCTURE_TIME/1000;
    target_time = VENEPUNCTURE_TIME;
    actuation_screen("Venepuncture");
  }
}

static void down_pressed(lv_event_t * event)
{
  //Original Code
  lv_event_code_t code = lv_event_get_code(event);

  if(code == LV_EVENT_PRESSED) 
  {
    occlusion_screen();
  }
}

static void timer_labelupdate(lv_timer_t* timer){
  sprintf(current_pressure_label, "%d", (int)current_pressure);
  lv_label_set_text(pressure_val, current_pressure_label);
}

static void timer_barupdate(lv_timer_t* timer){
  bar_value--;
}

static void timer_pressureupdate(lv_timer_t* timer){
  current_pressure = (mpr.readPressure() - calibration_value) * 0.75;

  PID_pressure = target_pressure;
  bool button_up = digitalRead(UP_BUTTON);
  bool button_down = digitalRead(DOWN_BUTTON);
  if (button_up == HIGH) {
    target_pressure = target_pressure + 1;
  } else if (button_down == HIGH) {
    target_pressure = target_pressure - 1;
  }

  char pressure_target[21]; 
  sprintf(pressure_target, "%d", (int)target_pressure);
  String target_pressure_label = (String)"Target Pressure: " + pressure_target + (String)" mmHg";
  char arr[target_pressure_label.length() + 1]; 
	strcpy(arr, target_pressure_label.c_str());
  lv_label_set_text(vene_label, arr);

  Input = current_pressure;
  myPID.Compute();
  
  if (timer_on == false) {
    analogWrite(MOTOR_PIN, Output);
  }
  
  if (current_pressure >= target_pressure-3 && time_started == false){
    start_time = millis();
    time_started = true;
  } else if (current_pressure < target_pressure-3){
    start_time = 0;
    time_started = false;
  }
  
  if (millis()-start_time > 5000 && time_started == true){
    lv_timer_resume(bar_timer);
    pressure_time = millis();
    analogWrite(MOTOR_PIN, 0);
    timer_on = true;
  }

  if (millis()-pressure_time >= target_time && timer_on){
    lv_timer_pause(bar_timer);
    timer_on = false;
  }

  if (current_pressure > target_pressure+10){
    digitalWrite(SOLENOID_PIN, HIGH);
  } else {
    digitalWrite(SOLENOID_PIN, LOW);
  }
  
  Serial.println(timer_on);
}

bool button_pressed(int button) {
  return digitalRead(button) == HIGH && digitalRead(button) == HIGH;
}

bool button_not_pressed(int button) {
  return digitalRead(button) == LOW && digitalRead(button) == LOW;
}

int my_btn_read(){
  if(button_pressed(UP_BUTTON) && button_not_pressed(DOWN_BUTTON)){
    return 0;
  }
  if(button_pressed(DOWN_BUTTON) && button_not_pressed(UP_BUTTON)){
    return 1;
  } else {
    return -1;
  }
}

void button_read( lv_indev_t * indev, lv_indev_data_t * data ){
  static uint32_t last_btn = 0;   /*Store the last pressed button*/
  int btn_pr = my_btn_read();     /*Get the ID (0,1,2...) of the pressed button*/
  if(btn_pr >= 0) {               /*Is there a button press? (E.g. -1 indicated no button was pressed)*/
      last_btn = btn_pr;           /*Save the ID of the pressed button*/
      data->state = LV_INDEV_STATE_PRESSED;  /*Set the pressed state*/
  } else {
      data->state = LV_INDEV_STATE_RELEASED; /*Set the released state*/
  }

  data->btn_id = last_btn;         /*Save the last button*/
}

static void set_arc_angle(void * obj, int32_t v)
{
  lv_arc_set_value((lv_obj_t*) obj, current_pressure);
}

static void set_bar_value(void * bar, int32_t v)
{
  lv_bar_set_value((lv_obj_t*) bar, bar_value, LV_ANIM_OFF);
}

void occlusion_screen(){

  int battery_level = analogRead(4);
  char battery_string[21]; 
  sprintf(battery_string, "%d", battery_level);

  lv_obj_t *screen = lv_obj_create(lv_screen_active());
  lv_obj_set_size(screen, TFT_HOR_RES, TFT_VER_RES);
  lv_obj_center(screen);
  lv_obj_clear_flag(screen, LV_OBJ_FLAG_SCROLLABLE);

  lv_obj_t * up = lv_imagebutton_create(screen);
  lv_imagebutton_set_src(up, LV_IMAGEBUTTON_STATE_RELEASED, NULL, &arrow_up, NULL);
  lv_obj_align(up, LV_ALIGN_CENTER, -50, -30);
  lv_obj_add_event_cb(up, occlusion_up_pressed, LV_EVENT_ALL, NULL);

  lv_obj_t * down = lv_imagebutton_create(screen);
  lv_imagebutton_set_src(down, LV_IMAGEBUTTON_STATE_RELEASED, NULL, &arrow_down, NULL);
  lv_obj_align(down, LV_ALIGN_BOTTOM_MID, -50, -20);
  lv_obj_add_event_cb(down, occlusion_down_pressed, LV_EVENT_ALL, NULL);

  lv_obj_t *menu_label = lv_label_create( screen );
  lv_label_set_text( menu_label, "Occlusion" );
  lv_obj_align( menu_label, LV_ALIGN_TOP_MID, -3, 0);

  static lv_style_t menu_style;
  lv_style_init(&menu_style);
  lv_style_set_text_font(&menu_style, &lv_font_montserrat_20); // <--- you have to enable other font sizes in menuconfig
  lv_obj_add_style(menu_label, &menu_style, 0);  // <--- obj is the label

  lv_obj_t *choose_label = lv_label_create( screen );
  lv_label_set_text( choose_label, "Please choose an");
  lv_obj_align( choose_label, LV_ALIGN_TOP_MID, -3, 30);
  lv_label_set_long_mode(choose_label, LV_LABEL_LONG_WRAP);

  lv_obj_t *device_label = lv_label_create( screen );
  lv_label_set_text( device_label, "occlusion mode");
  lv_obj_align( device_label, LV_ALIGN_TOP_MID, -3, 45);
  lv_label_set_long_mode(device_label, LV_LABEL_LONG_WRAP);

  static lv_style_t choose_style;
  lv_style_init(&choose_style);
  lv_style_set_text_font(&choose_style, &lv_font_montserrat_16); // <--- you have to enable other font sizes in menuconfig
  lv_obj_add_style(choose_label, &choose_style, 0);  // <--- obj is the label
  lv_obj_add_style(device_label, &choose_style, 0);  // <--- obj is the label

  lv_obj_t *vene_label = lv_label_create( screen );
  lv_label_set_text( vene_label, "Bicep Occlusion" );
  lv_obj_align( vene_label, LV_ALIGN_CENTER, 50, -35);

  lv_obj_t *occlusion_label = lv_label_create( screen );
  lv_label_set_text( occlusion_label, "Thigh Occlusion" );
  lv_obj_align( occlusion_label, LV_ALIGN_BOTTOM_MID, 50, -55);
  
  lv_obj_t *select_label = lv_label_create( screen );
  lv_label_set_text( select_label, "Select with up/down arrows" );
  lv_obj_align( select_label, LV_ALIGN_BOTTOM_MID, 0, 3);

  lv_obj_t *battery_label = lv_label_create( screen );
  lv_label_set_text( battery_label, battery_string LV_SYMBOL_BATTERY_3);
  lv_obj_align( battery_label, LV_ALIGN_TOP_RIGHT, 3, 0);

  char loc_time[9];
  sprintf(locTime, "%02d:%02d:%02d", timeinfo.tm_hour, timeinfo.tm_min, timeinfo.tm_sec);

  lv_obj_t *time_label = lv_label_create( screen );
  lv_label_set_text( time_label, loc_time);
  lv_obj_align( time_label, LV_ALIGN_TOP_LEFT, 0, 0);

  static lv_style_t vene_style;
  lv_style_init(&vene_style);
  lv_style_set_text_font(&vene_style, &lv_font_montserrat_14); // <--- you have to enable other font sizes in menuconfig
  lv_obj_add_style(vene_label, &vene_style, 0);  // <--- obj is the label
  lv_obj_add_style(occlusion_label, &vene_style, 0);
  lv_obj_add_style(select_label, &vene_style, 0);

  static lv_style_t time_style;
  lv_style_init(&time_style);
  lv_style_set_text_font(&time_style, &lv_font_montserrat_12); // <--- you have to enable other font sizes in menuconfig
  lv_obj_add_style(battery_label, &time_style, 0);  // <--- obj is the label
  lv_obj_add_style(time_label, &time_style, 0);
}

void home_screen(){

  int battery_level = analogRead(4);
  char battery_string[21]; 
  sprintf(battery_string, "%d", battery_level);

  lv_obj_t *screen = lv_obj_create(lv_screen_active());
  lv_obj_set_size(screen, TFT_HOR_RES, TFT_VER_RES);
  lv_obj_center(screen);
  lv_obj_clear_flag(screen, LV_OBJ_FLAG_SCROLLABLE);

  lv_obj_t * up = lv_imagebutton_create(screen);
  lv_imagebutton_set_src(up, LV_IMAGEBUTTON_STATE_RELEASED, NULL, &arrow_up, NULL);
  lv_obj_align(up, LV_ALIGN_CENTER, -50, -30);
  lv_obj_add_event_cb(up, up_pressed, LV_EVENT_ALL, NULL);

  lv_obj_t * down = lv_imagebutton_create(screen);
  lv_imagebutton_set_src(down, LV_IMAGEBUTTON_STATE_RELEASED, NULL, &arrow_down, NULL);
  lv_obj_align(down, LV_ALIGN_BOTTOM_MID, -50, -20);
  lv_obj_add_event_cb(down, down_pressed, LV_EVENT_ALL, NULL);

  lv_obj_t *menu_label = lv_label_create( screen );
  lv_label_set_text( menu_label, "Main Menu" );
  lv_obj_align( menu_label, LV_ALIGN_TOP_MID, -3, 0);

  static lv_style_t menu_style;
  lv_style_init(&menu_style);
  lv_style_set_text_font(&menu_style, &lv_font_montserrat_24); // <--- you have to enable other font sizes in menuconfig
  lv_obj_add_style(menu_label, &menu_style, 0);  // <--- obj is the label

  lv_obj_t *choose_label = lv_label_create( screen );
  lv_label_set_text( choose_label, "Please choose a");
  lv_obj_align( choose_label, LV_ALIGN_TOP_MID, -3, 30);
  lv_label_set_long_mode(choose_label, LV_LABEL_LONG_WRAP);

  lv_obj_t *device_label = lv_label_create( screen );
  lv_label_set_text( device_label, "device mode");
  lv_obj_align( device_label, LV_ALIGN_TOP_MID, -3, 45);
  lv_label_set_long_mode(device_label, LV_LABEL_LONG_WRAP);

  static lv_style_t choose_style;
  lv_style_init(&choose_style);
  lv_style_set_text_font(&choose_style, &lv_font_montserrat_16); // <--- you have to enable other font sizes in menuconfig
  lv_obj_add_style(choose_label, &choose_style, 0);  // <--- obj is the label
  lv_obj_add_style(device_label, &choose_style, 0);  // <--- obj is the label

  lv_obj_t *vene_label = lv_label_create( screen );
  lv_label_set_text( vene_label, "Venepuncture" );
  lv_obj_align( vene_label, LV_ALIGN_CENTER, 50, -35);

  lv_obj_t *occlusion_label = lv_label_create( screen );
  lv_label_set_text( occlusion_label, "Occlusion" );
  lv_obj_align( occlusion_label, LV_ALIGN_BOTTOM_MID, 40, -70);
  
  lv_obj_t *select_label = lv_label_create( screen );
  lv_label_set_text( select_label, "Select with up/down arrows" );
  lv_obj_align( select_label, LV_ALIGN_BOTTOM_MID, 0, 3);

  lv_obj_t *battery_label = lv_label_create( screen );
  lv_label_set_text( battery_label, battery_string LV_SYMBOL_BATTERY_3);
  lv_obj_align( battery_label, LV_ALIGN_TOP_RIGHT, 3, 0);

  char loc_time[9];
  sprintf(loc_time, "%02d:%02d:%02d", timeinfo.tm_hour, timeinfo.tm_min, timeinfo.tm_sec);

  lv_obj_t *time_label = lv_label_create( screen );
  lv_label_set_text( time_label, loc_time);
  lv_obj_align( time_label, LV_ALIGN_TOP_LEFT, 0, 0);

  static lv_style_t vene_style;
  lv_style_init(&vene_style);
  lv_style_set_text_font(&vene_style, &lv_font_montserrat_14); // <--- you have to enable other font sizes in menuconfig
  lv_obj_add_style(vene_label, &vene_style, 0);  // <--- obj is the label
  lv_obj_add_style(occlusion_label, &vene_style, 0);
  lv_obj_add_style(select_label, &vene_style, 0);

  static lv_style_t time_style;
  lv_style_init(&time_style);
  lv_style_set_text_font(&time_style, &lv_font_montserrat_12); // <--- you have to enable other font sizes in menuconfig
  lv_obj_add_style(battery_label, &time_style, 0);  // <--- obj is the label
  lv_obj_add_style(time_label, &time_style, 0);
}

void actuation_screen(const char *mode){
  lv_timer_t * pressure_timer = lv_timer_create(timer_pressureupdate, 50, NULL);
  lv_timer_ready(pressure_timer);

  lv_obj_t *screen = lv_obj_create(lv_screen_active());
  lv_obj_set_size(screen, TFT_HOR_RES, TFT_VER_RES);
  lv_obj_center(screen);
  lv_obj_clear_flag(screen, LV_OBJ_FLAG_SCROLLABLE);

  lv_obj_t *menu_label = lv_label_create( screen );
  lv_label_set_text( menu_label, mode );
  lv_obj_align( menu_label, LV_ALIGN_TOP_MID, 0, 0);

  static lv_style_t menu_style;
  lv_style_init(&menu_style);
  lv_style_set_text_font(&menu_style, &lv_font_montserrat_24); // <--- you have to enable other font sizes in menuconfig
  lv_obj_add_style(menu_label, &menu_style, 0);  // <--- obj is the label

  vene_label = lv_label_create( screen );
  lv_label_set_text( vene_label, "");
  lv_obj_align( vene_label, LV_ALIGN_CENTER, 0, 120);

  lv_obj_t * arc = lv_arc_create(screen);
  lv_arc_set_rotation(arc, 270);
  lv_arc_set_bg_angles(arc, 0, 360);
  lv_arc_set_range(arc, 0, target_pressure);
  lv_obj_remove_style(arc, NULL, LV_PART_KNOB);   /*Be sure the knob is not displayed*/
  lv_obj_remove_flag(arc, LV_OBJ_FLAG_CLICKABLE);  /*To not allow adjusting by click*/
  lv_obj_align(arc, LV_ALIGN_CENTER, 0, -20);

  lv_anim_t a;
  lv_anim_init(&a);
  lv_anim_set_var(&a, arc);
  lv_anim_set_exec_cb(&a, set_arc_angle);
  lv_anim_set_duration(&a, 1000);
  lv_anim_set_repeat_count(&a, LV_ANIM_REPEAT_INFINITE);
  lv_anim_set_repeat_delay(&a, 500);
  lv_anim_start(&a);

  pressure_val = lv_label_create( screen );
  lv_label_set_text(pressure_val, "");
  lv_obj_align(pressure_val, LV_ALIGN_CENTER, 0, -20);
  
  static lv_style_t pressure_label_style;
  lv_style_init(&pressure_label_style);
  lv_style_set_text_font(&pressure_label_style, &lv_font_montserrat_24); // <--- you have to enable other font sizes in menuconfig
  lv_obj_add_style(pressure_val, &pressure_label_style, 0);  // <--- obj is the label

  bar = lv_bar_create(lv_screen_active()); 
  lv_obj_set_size(bar, 200, 20);
  lv_obj_align(bar, LV_ALIGN_BOTTOM_MID, 0, -70);
  lv_bar_set_value(bar, 100, LV_ANIM_OFF);
  lv_bar_set_range(bar, 0, bar_value);
  // lv_obj_add_event_cb(bar, event_cb, LV_EVENT_DRAW_MAIN_END, NULL);

  lv_anim_t bar_anim;
  lv_anim_init(&bar_anim);
  lv_anim_set_var(&bar_anim, bar);
  lv_anim_set_values(&bar_anim, 0, bar_value);
  lv_anim_set_exec_cb(&bar_anim, set_bar_value);
  lv_anim_set_duration(&bar_anim, 4000);
  lv_anim_set_playback_duration(&bar_anim, 4000);
  lv_anim_set_repeat_count(&bar_anim, LV_ANIM_REPEAT_INFINITE);
  lv_anim_start(&bar_anim);

  lv_timer_t * label_timer = lv_timer_create(timer_labelupdate, 500, NULL);
  lv_timer_ready(label_timer);

  bar_timer = lv_timer_create(timer_barupdate, 1000,  NULL);
  lv_timer_pause(bar_timer);
}

void print_local_time()
{
  if(!getLocalTime(&timeinfo)){
    Serial.println("Failed to obtain time");
    return;
  }
  Serial.println(&timeinfo, "%A, %B %d %Y %H:%M:%S");
}

void setup()
{
  String LVGL_Arduino = "Hello Arduino! ";
  LVGL_Arduino += String('V') + lv_version_major() + "." + lv_version_minor() + "." + lv_version_patch();

  pinMode(MOTOR_PIN, OUTPUT);
  pinMode(SOLENOID_PIN, OUTPUT);
  pinMode(BL_PIN, OUTPUT);
  pinMode(UP_BUTTON, INPUT);
  pinMode(DOWN_BUTTON, INPUT);
  pinMode(SLEEP_PIN, OUTPUT);
  pinMode(STATUS_LED, OUTPUT);
  pinMode(POWER_LED, OUTPUT);

  digitalWrite(SOLENOID_PIN, LOW);
  digitalWrite(MOTOR_PIN, LOW);
  digitalWrite(BL_PIN, HIGH);
  digitalWrite(SLEEP_PIN, HIGH);
  digitalWrite(POWER_LED, HIGH);

  Serial.begin(115200);
  Wire.begin(1,2);
  Serial.println(LVGL_Arduino);

  if (! mpr.begin()) {
    Serial.println("Failed to communicate with MPRLS sensor, check wiring?");
    while (1) {
        digitalWrite(STATUS_LED, HIGH);
        delay(10);
    }
  }

  // initialize time
  Serial.printf("Connecting to %s ", ssid);
  digitalWrite(STATUS_LED, HIGH);
  WiFi.begin(ssid, password);
  while (WiFi.status() != WL_CONNECTED) {
      delay(500);
      Serial.print(".");
  }
  Serial.println(" CONNECTED");

  configTime(gmt_offset_sec, daylight_offset_sec, ntp_server);

  print_local_time();
  digitalWrite(STATUS_LED, LOW);

  WiFi.disconnect(true);
  WiFi.mode(WIFI_OFF);

  calibration_value = mpr.readPressure();

  // Initialize PID controller
  myPID.SetMode(AUTOMATIC);
  myPID.SetOutputLimits(0, 255); // PWM range for motor control

  lv_init();

  /*Set a tick source so that LVGL will know how much time elapsed. */
  lv_tick_set_cb(my_tick);

  lv_display_t * disp;
  /*TFT_eSPI can be enabled lv_conf.h to initialize the display in a simple way*/
  disp = lv_tft_espi_create(TFT_HOR_RES, TFT_VER_RES, draw_buf, sizeof(draw_buf));
  lv_display_set_rotation(disp, TFT_ROTATION);

  lv_indev_t * button_indev = lv_indev_create();
  lv_indev_set_type(button_indev, LV_INDEV_TYPE_BUTTON);
  lv_indev_set_read_cb(button_indev, button_read);
  static lv_point_t button_array[2] = { { 70, 130 }, {70, 280} };
  lv_indev_set_button_points(button_indev, button_array);

  Serial.println( "Setup done" );

  lvgl_refresh_timestamp = millis();

  home_screen();
}

static void LVGL_TaskMng( void )
{
  uint32_t now = millis();
  // LVGL Refresh Timed Task
  if( (now - lvgl_refresh_timestamp) >= LVGL_REFRESH_TIME )
  {
    lvgl_refresh_timestamp = now;
    // let the GUI does work
    lv_timer_handler();
  }
}

void loop()
{
  LVGL_TaskMng(); /* let the GUI do its work */
}

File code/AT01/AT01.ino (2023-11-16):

/*
Adafruit Arduino - Lesson 13. DC Motor
*/

#include "HX710B.h"
#include <stdio.h>
#include "xc.h"
#include <p24FJ128GA010.h> // for microcontroller
#include <assert.h>

HX710B pressure_sensor;

int motorPin = 5;
// 1. Declaration of macros and global variables
#define BUTTON _RB8 // change pin number for button as per need 
#define BUTTON_PRESSED() (BUTTON == 0)    // button pressed state
#define BUTTON_RELEASED() (BUTTON == 1)   // button released state
#define LED _RE5 // LED
int TargetPressure, maxTime; 


// 2. Function prototypes
void msDelay(int msec); // declare msDelay function
void UsageMode; // declare UsageMode function
void TargetLimb; // declare TargetLimb function

int main() {
    // 3. Initialization
    AD1PCFG = 0xFFFF;            // Port B pins are set to digital
    CNPU1 = 0x0000;              // No internal (weak) pull-up
    // TRISB binary: 0000 0000 0000 0001, (RB0-RB5 as input, high); hex: 0 0 0 1; 
    // TRISB 
    TRISB = 0x0001; 
    // TRISE binary: 0000 0000 0000 0000, (RE0-RE2 as output, or all as low)
    // TRISE hex: 0 0 0 0
    TRISE = 0; 

    msDelay (50); // wait a few seconds for user to press
    // stage 1: determine usage mode 
    UsageMode(); // call usage mode function
    if (UsageMode() = "OCCLUSION"){
        TargetLimb(); // // call target limb function
    }
    else if (UsageMode() = "VENIPUNCTURE"){
        TargetPressure = 60; // [mmHg] 
        maxTime = 60; // [s], or 1/60 [h]
    }
    else{ // no usage mode determined, try again
        UsageMode(); // call usage mode function
    }
    
    // stage 2: determine target limb 
    if (TargetLimb() = "BICEP"){
        ***
    }
    else if (TargetLimb() = "THIGH"){
        ***
    }
    else{ // no usage mode determined, try again
        TargetLimb(); // call target limb function
    }
    
    return 0;
}

void msDelay (int msec){ // Function 1: Delay Function 
    int m,n;
    for(m=0;m<msec;m++){
        for(n=0;n<50;n++){
        }
    }
}

void UsageMode { // Function 2: checking button for mode of usage
    printf("Please select Mode of Usage: press button for 'Occlusion', or leave unpressed for 'Venipuncture'");
    msDelay(50); // wait for user to select mode
    char Mode[]; 
    while(1){
        if (BUTTON_PRESSED()){
            printf("You have selected: 'Occlusion', please press again to confirm."); 
            msDelay(50); // wait for user to confirm
            if(BUTTON_PRESSED()){
                printf("'Occlusion' Mode is confirmed."); 
                Mode = "OCCLUSION";
                break;
            }
            else{
                printf("'Occlusion' Mode NOT confirmed, please try again."); 
                Mode = "";
                break; // how to bring back to selection stage? 
            }
        }
        else{
            printf("You have selected: 'Venipuncture', please press again to confirm."); 
            msDelay(50); // wait for user to confirm
            if(BUTTON_PRESSED()){
                printf("'Venipuncture' Mode is confirmed."); 
                Mode = "VENIPUNCTURE";
                break;
            }
            else{
                printf("'Venipuncture' Mode NOT confirmed, please try again."); 
                Mode = "";
                break; // how to bring back to selection stage? 
            }
        }
    }
    return Mode; // output of function
} // end of UsageMode function

void TargetLimb { // Function 3: checking button for limb of usage
    printf("Please select Limb of Usage: press button for 'Bicep', or leave unpressed for 'Thigh'");
    msDelay(50); // wait for user to select mode
    char Limb[]; 
    while(1){
        if (BUTTON_PRESSED()){
            printf("You have selected: 'Thigh', please press again to confirm."); 
            msDelay(50); // wait for user to confirm
            if(BUTTON_PRESSED()){
                printf("'Thigh' Occlusion Mode is confirmed."); 
                Limb = "THIGH";
                TargetPressure = 300; // [mmHg]
                maxTime = 7200; // [s], or 2 [h]
                break;
            }
            else{
                printf("'Thigh' Occlusion Mode NOT confirmed, please try again."); 
                Limb = "";
                break; // how to bring back to selection stage? 
            }
        }
        else{
            printf("You have selected: 'Bicep', please press again to confirm."); 
            msDelay(50); // wait for user to confirm
            if(BUTTON_PRESSED()){
                printf("'Bicep' Occlusion Mode is confirmed."); 
                Limb = "BICEP";
                TargetPressure = 203; // [mmHg]
                maxTime = 5400; // [s], or 1.5 [h]
                break;
            }
            else{
                printf("'Bicep' Occlusion Mode NOT confirmed, please try again."); 
                Limb = "";
                break; // how to bring back to selection stage? 
            }
        }
    }
    return Limb, TargetPressure, maxTime; // outputs of function
} // end of TargetLimb function

// int detectPressure(){
//     // wait for the current reading to finish
//   while (digitalRead(2)) {}

//   // read 24 bits
//   long result = 0;
//   for (int i = 0; i < 24; i++) {
//     digitalWrite(3, HIGH);
//     digitalWrite(3, LOW);
//     result = result << 1;
//     if (digitalRead(2)) {
//       result++;
//     }
//   }

//   // get the 2s compliment
//   result = result ^ 0x800000;

//   // pulse the clock line 3 times to start the next pressure reading
//   for (char i = 0; i < 3; i++) {
//     digitalWrite(3, HIGH);
//     digitalWrite(3, LOW);
//   }
//     // display pressure
//   Serial.println(result);
//   return result;
// }


void setup() 
{ 
  pinMode(motorPin, OUTPUT);
  pinMode(2, INPUT);   // Connect HX710 OUT to Arduino pin 2
  pinMode(3, OUTPUT);  // Connect HX710 SCK to Arduino pin 3
  Serial.begin(9600);
  while (! Serial);
  Serial.println("Speed 0 to 255");
} 
 
 
void loop() 
{   
  if (Serial.available())
  {
    int speed = Serial.parseInt();
    if (speed >= 0 && speed <= 255)
    {
      int pressure = 5;
      while(pressure != 4){
        analogWrite(motorPin, speed);
        pressure = pressure_sensor.mmHg();
        Serial.println(pressure);
      }
    }
  }
}

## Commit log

2023-10-27 Initial Schematic Commit
    [AT01_Schematic.kicad_pcb, AT01_Schematic.kicad_sch]
2023-11-02 Preliminary Schematic
    this schematic is probably wrong, im working on adding battery power at 3.3v regulated and the motor into the schematic. still needs a lot of work
    [AT01.kicad_pcb, AT01.sch]
2023-11-02 old preliminary upload didn't work, uploading again
    [AT01.kicad_pcb, AT01.sch]
2023-11-03 restructuring directories and adding initial inflation code
    [AT01.kicad_pcb, AT01.sch, AT01_Schematic.kicad_pcb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]
2023-11-03 removing old versions of file
    [AT01.kicad_sch, AT01.sch]
2023-11-08 added pressure sensor circuit
    [AT01.kicad_sch]
2023-11-08 adding power supply circuit to schematic
    [AT01.kicad_sch]
2023-11-08 adding pressure sensor and diode libs
    [DMG3415U-7.step]
2023-11-15 adding motor drive schematic
    [AT01.kicad_sch]
2023-11-16 fixing motor driver schematic and adding reset schematic
    [AT01.kicad_sch]
2023-11-16 completed initial schematic development
    [AT01.kicad_sch]
2023-12-01 adding libs, cleaning up sch, initial pcb commit
    [AT01.csv, AT01.kicad_pcb, AT01.kicad_sch]
2023-12-19 fixing up labels, gnds, added some protection diodes
    [AT01.kicad_pcb, AT01.kicad_sch]
2023-12-19 fixing major issue with the LDO
    [AT01.kicad_sch]
2023-12-21 reddit fixes, adding buttons/leds, restarting pcb layout
    [AT01.kicad_pcb, AT01.kicad_sch]
2024-01-06 initial layout revision
    [AT01.kicad_pcb, AT01.kicad_sch]
2024-01-08 DRC fixes
    [AT01.kicad_pcb]
2024-01-11 updated incorrect UART pins
    [AT01.kicad_pcb, AT01.kicad_sch]
2024-01-13 adding working code for prototype
2024-01-15 moving gnd panel to back copper, button modifications
    [AT01.kicad_pcb, AT01.kicad_sch]
2024-01-17 adding working code for sensor, screen, project config settings
2024-01-19 adding board with direct USB-C connection, esp32-s3 based
    [AT01.kicad_pcb, AT01_no_ftdi.kicad_pcb, AT01_no_ftdi.kicad_sch]
2024-01-25 added redesigned charging circuit
    [AT01.csv, AT01.kicad_pcb, AT01.kicad_sch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]
2024-01-25 adding 2nd page of AT01 sch
    [AT01_Lipo.kicad_sch]
2024-01-25 adding library files and datasheets
    [FDS6375.step]
2024-01-26 PCB redesign for new charging circuit with Espressif recommendations
    [AT01_no_ftdi.kicad_pcb, AT01_no_ftdi.kicad_sch]
2024-01-26 adding NC for pin 25, 26
    [AT01_no_ftdi.kicad_pcb]
2024-01-27 updated FTDI board
    [AT01.kicad_pcb, AT01.kicad_sch, AT01_no_ftdi.kicad_pcb]
2024-01-27 adding testing PCBs with external batteries
    [AT01_no_ftdi_testing.kicad_pcb, AT01_no_ftdi_testing.kicad_sch, AT01_testing.kicad_pcb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]
2024-01-28 adding design recommendations from call with Yi
    [AT01.kicad_sch, AT01_Lipo.kicad_sch, AT01_no_ftdi.kicad_pcb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]
2024-01-29 adding SSR and new ESD protection diodes according to design review
    [AT01_no_ftdi.kicad_pcb, AT01_no_ftdi.kicad_sch]
2024-01-29 added random vias on board for better cap control
    [AT01_no_ftdi.kicad_pcb]
2024-02-02 added simple control system and button functionality
2024-02-15 final rev1.0 design
    [AT01_no_ftdi.kicad_pcb, AT01_no_ftdi.kicad_sch]
2024-03-14 reworking usb c connection
    [AT01_no_ftdi.kicad_pcb, AT01_no_ftdi.kicad_sch]
2024-03-22 new code and some schematic work
    [AT01_no_ftdi.kicad_sch]
2024-03-22 removing pressure: psi line to adjust to format
2024-03-22 Added MATLAB Pressure Plotting Script
2024-03-23 Adding interrupt testing code
2024-04-04 adding PID control to main.cpp
2024-04-05 final working PID implementation
2024-04-05 updating load sharing circuit
    [AT01_no_ftdi-B_Adhesive.gbr, AT01_no_ftdi-B_Courtyard.gbr, AT01_no_ftdi-B_Cu.gbr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]
2024-04-05 menu and PID integration
2024-04-07 Revised PID and Menu code
2024-04-07 Rev3.0 board commits
    [AT01_no_ftdi.kicad_pcb, AT01_no_ftdi.kicad_sch]
2024-04-11 final rev1.0 commit
    switching bicep and thigh occlusion buttons
2024-04-25 fixed actuation screen, arc and labels both work now
    [main.cpp]
2024-04-26 intergrated PID, added ability to change target pressure
2024-04-26 added pressure timer
2024-04-26 added leds
2024-05-07 STL readme creation
2024-05-07 adding cad stl files
    [AT01 - battery cover.stl, AT01 - bottom.stl, AT01 - button setter.stl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]
